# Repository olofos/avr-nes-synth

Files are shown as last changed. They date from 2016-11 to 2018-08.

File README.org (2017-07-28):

* NESSynth

  /NESSynth/ is an overcomplicated machine that plays NES music. /NESSynth/ currently supports four of the five channels present in the NES Audio Processing Unit (APU):
  - Two pulse, or square wave, channels
  - A triangle wave
  - A random noise channel

  There is currently no support for a DCM channel.

  /NESSynth/ has a menu system where the user can choose which game soundtrack is to be played.
  There is furthermore support for a playlist to which individual tracks can be added and played back.

** Hardware overview

  Each *channel* is processed separately by firmware running on an 8-bit ATMega88p microcontroller.
  An ATMega328p microcontroller acts as a central *controller*, reading track information from an SD card and writing the corresponding instructions to the channels.
  The controller is furthermore connected to an 128x64 pixel SSD1306 OLED display on which information about the current track, as well as a simple menu system, is displayed.
  User input is processed through an additional ATMega88p microcontroller which acts like an *io-bridge*, communicating with the main controller over I2C.
  The io-bridge is connected to four user buttons, four LEDs an a UART header for debugging.

  The following block diagram gives an overview of the architecture of /NESSynth/.

  #+HTML: <a href="doc/block-diagram.png"><img src="doc/block-diagram.png" width=800px></a>

*** 8-bit bus

   The controller communicates with the channels using an *8-bit parallel bus*.
   Writes to the bus are signalled on the *data clock* line.
   A rising clock signals that an address has been written on the bus, and a falling clock signals that a value that is to be written to the register at the previous address has been written on the bus.
   A new address or value is written every 33us, and the channels have to ensure that the data has been read from the bus within that time frame.

*** Frame clock

   In addition to the 8-bit bus, the controller provides the channel with a frame clock, which fires at a constant rate of 240 Hz.
   The frame clock is used to regularly update the output wave forms by applying the various effects such as the length counters and sweep units.

*** Channels

   Each channel emulates one of the channels on the NES APU.
   They react to writes to the corresponding registers appearing on the data bus and at each tick of the frame clock they clock the relevant output units in order to create effects such as sweep and envelope decay.

   The channels output sound at a frequency that is obtained by dividing the NTSC APU frequency of 1.789773 MHz by an integer, the /period/.
   The microcontrollers in the channels are clocked using a crystal with resonant frequency 14.3818 MHz, which is a multiple of the APU frequency.

   The PCBs of the channels have two jumpers, *CONF0* and *CONF1*, which can be used to configure which of the four APU channels the microcontroller is emulating.
   The possible settings are given in the following table.

   | CONF1      | CONF0      | Channel        |
   |------------+------------+----------------|
   | Fitted     | Fitted     | Square wave #1 |
   | Fitted     | Not fitted | Square wave #2 |
   | Not fitted | Fitted     | Triangle wave  |
   | Not fitted | Not fitted | Noise          |

   Each channel has a four bit R2R DAC that is used to construct the outgoing audio wave form.

   - Square wave channels

     The two square wave channels output a square wave with a duty cycle that can be set to 12.5%, 25%, 50% or 75%. The output volume of the square wave channels can be set to one of 16 levels, and can be modulated using the envelope decay unit. The square wave channels further support a sweep function to modulate the output frequency, as well as a length counter.

   - Triangle wave

     The triangle wave channel outputs a 32-step triangle wave of constant volume. For a given period, the frequency of the triangle wave is half of that of a square wave of the same period. The triangle wave channel supports a length counter and a linear counter which both can be used to limit the amount of time a note is played.

   - Noise channel

     The noise channel outputs noise that is generated using a linear feedback shift register. The feedback can be taken from two different taps of the shift registers. The volume of the noise channel can be configured to be constant, with 16 possible output levels, or can be varied over time using the envelope decay unit. The noise channel also supports a length counter.

*** Audio output

    The output of each channel is mixed together and then passed through a low pass filter with corner frequency 16 Hz and a high pass filter with corner frequency 16 kHz.
    The signal is the amplified using an LM386 audio amplifier before going to an 8 ohm speaker.

** Firmware

   The firmware for /NESSynth/ consists of three main pieces: the firmware for the main controller, the io-bridge and for the channels.
   The firmware is written using [[http://www.nongnu.org/avr-libc/user-manual/][avr-libc]] and compiled using avr-gcc.

   The controller has a menu system which is displayed on the OLED display.
   The menu system supports menus stored either on an SD card, in the flash memory of the controller, or in the EEPROM.
   It allows the user to play all the tracks from a particular game or to create a playlist with up to 128 tracks.
   The playlist is stored in the EEPROM of the controller.

   When playing a track, the controller reads the song data from the SD card where it is stored in a custom binary format (see below).
   The song data records the state of the APU registers at 60 Hz, and the controller outputs the data on the 8-bit bus.
   The song data is split into frames, and the controller plays the frames back at 60 Hz.

   The controller firmware includes a custom SD card and FAT32 drivers.
   The FAT32 driver does not read the FAT table into memory, which means that it has to search the table while reading data off the SD card.
   To improve performance when seeking in small files there is a cluster cache where the first few clusters in the currently open file.

   The firmware of the channels simply listens to writes to the registers relevant to the corresponding APU channel and puts out a wave form on the DAC.
   The channel firmware is heavily interrupt based.
   In order to improve the performance of the main timer interrupt, which is responsible for actually constructing the audio out signal, the interrupt handler has been written in assembly code.
   For clarity there is also a C version of the interrupt handler, which can be enabled by removing the ASMINTERRUPT flag in the Makefile of the channel firmware source code.

*** Song file format

   The binary file format is very simple.
   It consists of a number of two-byte records, with the first byte indicating an address, and the second byte the corresponding values.
   There are three special records

   | Address | Value | Meaning      |
   |---------+-------+--------------|
   |    0xF1 |  0xF1 | End of frame |
   |    0xFF |  0xFF | End of file  |
   |    0xFE |  0xFE | Loop         |

   The loop record is followed by a 16-bit byte address indicating which byte in the file to loop back to.

   In order to construct a data file from an NSF files, a player based on a custom version of the [[http://www.slack.net/~ant/libs/audio.html#Game_Music_Emu][Game_Music_Emu 0.5.2]] library is used.
   The custom NSF player outputs data in a text file.
   This data is then processed through a couple of simple programs which are used to detect loops in the track, and to convert the data into the binary file format described above.

** Acknowledgements

   The [[https://wiki.nesdev.com/w/index.php/APU][APU pages]] of the [[https://wiki.nesdev.com/][NesDev wiki]] have been invaluable for providing information about the inner workings of the NES APU, as has the [[http://nesdev.com/NESSOUND.txt][NESSOUND]] document by Brad Taylor.

   The NSF player that is used to create binary sound data files is based on the  [[http://www.slack.net/~ant/libs/audio.html#Game_Music_Emu][Game_Music_Emu 0.5.2]] library by Shay Green, which is licensed under the [[https://www.gnu.org/licenses/old-licenses/lgpl-2.1.en.html][GNU Lesser General Public License, Version 2.1]].

   The circular buffer implementation in lib/cbuf.h is inspired by the one in [[https://github.com/dhylands/TimerUART][TimerUART]].

   For 3d rendering of the boards, 3d models from [[https://github.com/ab2tech/KiCad][ab2tech]], which are licensed under [[http://creativecommons.org/licenses/by-nc-sa/3.0/deed.en_US][Creative Commons Attribution-NonCommercial-ShareAlike 3.0 Unported License]], and from [[https://github.com/JorgeAparicio/libKiCad][libKiCad]], which are licensed under [[hardware/lib/3d_models/walter/license.txt][Creative Commons license v3.0, Attribution-Share Alike]], have been used.

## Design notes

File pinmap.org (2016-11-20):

* Main board
  PB0 DCLK
  PB1 SD_CD
  PB2 SD_CS
  PB3 MOSI
  PB4 MISO
  PB5 SCK

  PC0 IO_INT
  PC1 LED
  PC2 CH_RESET
  PC3 FCLK
  PC4 SDA
  PC5 SCL

  PD0 BUS0 + RX
  PD1 BUS1
  PD2 BUS2
  PD3 BUS3
  PD4 BUS4
  PD5 BUS5
  PD6 BUS6
  PD7 BUS7

* IO board
  PB0 SW1
  PB2 SW2
  PB6 SW3
  PB7 SW4

  PC0 LED1
  PC1 LED2
  PC2 LED3
  PC3 LED4
  PC4 SDA
  PC5 SCL

  PD0 RX
  PD1 TX
  PD2 IO_INT

* Channel
  PB0 DCLK
  PB1 CONF0
  PB2 CONF1
  
  PC0 DAC0
  PC1 DAC1
  PC2 DAC2
  PC3 DAC3
  PC4 LED
  PC5 FCLK

  PD0 BUS0
  PD1 BUS1
  PD2 BUS2
  PD3 BUS3
  PD4 BUS4
  PD5 BUS5
  PD6 BUS6
  PD7 BUS7

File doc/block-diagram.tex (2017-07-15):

\documentclass{standalone}

\usepackage{tikz}
\usetikzlibrary{arrows,calc,shapes}

\renewcommand{\familydefault}{\sfdefault}

\tikzstyle{block} = [draw,rounded corners,fill=blue!20,inner sep=0pt]
\tikzstyle{io-block} = [draw,rounded corners,fill=red!20,inner sep=0pt]
\tikzstyle{mixer} = [regular polygon, regular polygon sides=3,draw, fill=blue!20, text width=1em,inner sep=1mm, outer sep=0mm, shape border rotate=-90]

\begin{document}

\begin{tikzpicture}
%  \draw (-10,-1.75) rectangle (4.9,7.2);
  
  \node [block,minimum width=4cm,minimum height=1.75cm] (controller) at (0,0) {\parbox{1.4cm}{\centering controller \\ \tiny atmega328p}};
  \node [block,minimum width=1.75cm,minimum height=1.75cm] (io-bridge) at (-7,0) {\parbox{1.4cm}{\centering io-bridge \\ \tiny atmega88p}};

  \node [block,minimum width=1.75cm,minimum height=1.75cm] (channel-1) at (-8,4) {\parbox{1.75cm}{\centering channel 1 \\ \tiny atmega88p}};
  \node [block,minimum width=1.75cm,minimum height=1.75cm] (channel-2) at (-6,4) {\parbox{1.75cm}{\centering channel 2 \\ \tiny atmega88p}};
  \node [block,minimum width=1.75cm,minimum height=1.75cm] (channel-3) at (-4,4) {\parbox{1.75cm}{\centering channel 3 \\ \tiny atmega88p}};
  \node [block,minimum width=1.75cm,minimum height=1.75cm] (channel-4) at (-2,4) {\parbox{1.75cm}{\centering channel 4 \\ \tiny atmega88p}};

  \node [io-block,minimum width=0.9cm,minimum height=0.4cm] (OLED) at ($(controller.west)!0.5!(io-bridge.east)-(0,1.5)$) {\tiny OLED};
  \node [io-block,minimum width=0.9cm,minimum height=0.4cm] (UART) at ($(io-bridge)+(1.5,-1.5)$) {\tiny UART};
  \node [io-block,minimum width=0.9cm,minimum height=0.4cm] (LEDs) at ($(io-bridge)+(0,-1.5)$) {\tiny LEDs};
  \node [io-block,minimum width=0.9cm,minimum height=0.4cm] (buttons) at ($(io-bridge)+(-1.5,-1.5)$) {\tiny buttons};

  \coordinate (controller-i2c-c) at (controller.west);
  \coordinate (controller-spi-c) at (controller.east);
  \coordinate (controller-bus-c) at ($(controller.north)+(-0.55,0)$);
  \coordinate (controller-dclk-c) at ($(controller.north)+(-1.7,0)$);
  \coordinate (controller-fclk-c) at ($(controller.north)+(+0.55,0)$);
  \coordinate (controller-ch-res-c) at ($(controller.north)+(+1.7,0)$);
  \coordinate (controller-io-int-c) at ($(controller.west)+(0,0.5)$);

  \coordinate (io-bridge-spi-c) at ($(io-bridge.west)+(0,0.5)$);
  \coordinate (io-bridge-buttons-c) at ($(io-bridge.west)-(0,0.5)$);
  \coordinate (io-bridge-UART-c) at ($(io-bridge.east)-(0,0.5)$);
  \coordinate (io-bridge-LEDs-c) at (io-bridge.south);
  \coordinate (io-bridge-io-int-c) at ($(io-bridge.east)+(0,0.5)$);

  \node [mixer] (mixer) at (0,6.5) {};
  \node at ($(mixer)-(0,0)$) {\tiny mixer};

  \coordinate (audio-out-1) at ($(mixer.west)+(0,0.375)$);
  \coordinate (audio-out-2) at ($(mixer.west)+(0,0.125)$);
  \coordinate (audio-out-3) at ($(mixer.west)-(0,0.125)$);
  \coordinate (audio-out-4) at ($(mixer.west)-(0,0.375)$);

  \foreach \n in {1,2,3,4} {
    \coordinate (channel-\n-dclk) at ($(channel-\n.south)+(-0.5,0)$);
    \coordinate (channel-\n-bus) at ($(channel-\n.south)+(-0.125,0)$);
    \coordinate (channel-\n-fclk) at ($(channel-\n.south)+(+0.125,0)$);
    \coordinate (channel-\n-reset) at ($(channel-\n.south)+(+0.5,0)$);

    \coordinate (channel-\n-spi-c) at ($(channel-\n.north)+(-0.5,0)$);
    \coordinate (channel-\n-audio-c) at ($(channel-\n.north)+(+0.5,0)$);

    \node (channel-\n-spi) at ($(channel-\n-spi-c)+(0,0.1)$) [draw,rounded corners,anchor=south] {\tiny SPI};
    \node (channel-\n-audio) at ($(channel-\n-audio-c)+(0,0.1)$) [draw,rounded corners,anchor=south] {\tiny audio};

    \draw (channel-\n-spi-c) -- (channel-\n-spi);
    \draw (channel-\n-audio-c) -- (channel-\n-audio);

    \node [io-block,minimum width=0.9cm,minimum height=0.4cm] (channel-\n-ISP) at ($(channel-\n-spi.north)+(0,0.5)$) {\tiny ISP};
    \draw [<->] (channel-\n-spi) -- (channel-\n-ISP);

    \draw [rounded corners,->] (channel-\n-audio) |- (audio-out-\n);
  }

  \node [io-block,minimum width=1.2cm,minimum height=0.4cm] (audio-out) at ($(mixer.east)+(1.5,0)$) {\tiny audio out};

  \draw [->] (mixer.east) -- (audio-out);

  \node (controller-i2c) at ($(controller-i2c-c)+(-0.1,0)$) [draw,rounded corners,anchor=east] {\tiny I2C};
  \node (controller-spi) at ($(controller-spi-c)+(+0.1,0)$) [draw,rounded corners,anchor=west] {\tiny SPI};

  \node [io-block,minimum width=0.9cm,minimum height=0.4cm] (SD-card) at ($(controller-spi)+(1,-1.5)$) {\tiny SD card};
  \node [io-block,minimum width=0.9cm,minimum height=0.4cm] (controller-ISP) at ($(controller-spi)+(2,0)$) {\tiny ISP};

  \node (io-bridge-spi) at ($(io-bridge-spi-c)+(-0.1,0)$) [draw,rounded corners,anchor=east] {\tiny SPI};

  \node [io-block,minimum width=0.9cm,minimum height=0.4cm] (io-bridge-ISP) at ($(io-bridge-spi)-(1.25,0)$) {\tiny ISP};
  
  \node (controller-bus) at ($(controller-bus-c)+(0,0.1)$) [draw,rounded corners,anchor=south] {\parbox{0.75cm}{\centering \tiny 8-bit \\ bus}};
  \node (controller-dclk) at ($(controller-dclk-c)+(0,0.1)$) [draw,rounded corners,anchor=south] {\parbox{0.75cm}{\centering \tiny Data \\ clock}};
  \node (controller-fclk) at ($(controller-fclk-c)+(0,0.1)$) [draw,rounded corners,anchor=south] {\parbox{0.75cm}{\centering \tiny Frame \\ clock}};
  \node (controller-ch-res) at ($(controller-ch-res-c)+(0,0.1)$) [draw,rounded corners,anchor=south] {\parbox{0.85cm}{\centering \tiny Channel \\ reset}};
  \node (controller-io-int) at ($(controller-io-int-c)-(0.1,0)$) [draw,rounded corners,anchor=east] {\parbox{0.75cm}{\centering \tiny IO int}};

  \draw (controller-spi-c) -- (controller-spi);
  \draw (controller-i2c-c) -- (controller-i2c);
  \draw (controller-dclk-c) -- (controller-dclk);
  \draw (controller-fclk-c) -- (controller-fclk);
  \draw (controller-ch-res-c) -- (controller-ch-res);
  \draw (controller-io-int-c) -- (controller-io-int);

  \draw [->] (io-bridge-io-int-c) -- (controller-io-int);

  \draw (io-bridge-spi-c) -- (io-bridge-spi);

  \foreach \x in {-0.35, -0.25, -0.15, -0.05, 0.05, 0.15, 0.25, 0.35} {
    \draw ($(controller-bus-c)+(\x,0)$) -- ($(controller-bus.south)+(\x,0)$);
  }
  
  \draw [<->] ($(controller-i2c.west)+(0,0.05)$) -- ($(io-bridge.east)+(0,0.05)$);
  \draw [rounded corners,->] ($(controller-i2c.west)-(0,0.05)$) -| (OLED.north);

  \draw [rounded corners,<->] (controller-spi.east) -| (SD-card.north);
  \draw [rounded corners,->] (controller-spi.east) -- (controller-ISP.west);

  \draw [rounded corners,<->] (io-bridge-spi.west) -- (io-bridge-ISP.east);

  \draw [rounded corners,<->] (io-bridge-UART-c) -| (UART);
  \draw [rounded corners,->] (io-bridge-LEDs-c) -- (LEDs);
  \draw [rounded corners,<-] (io-bridge-buttons-c) -| (buttons);

  \foreach \n in {1,2,3,4} {
    \draw [rounded corners,->] (controller-dclk.north) -- ($(controller-dclk.north)+(0,0.5)$) -| (channel-\n-dclk);
    \draw [rounded corners,->] (controller-bus.north) -- ($(controller-bus.north)+(0,0.75)$) -| (channel-\n-bus);
    \draw [rounded corners,->] (controller-fclk.north) -- ($(controller-fclk.north)+(0,1)$) -| (channel-\n-fclk);
    \draw [rounded corners,->] (controller-ch-res.north) -- ($(controller-ch-res.north)+(0,1.25)$) -| (channel-\n-reset);
  }

  \coordinate (sw) at (current bounding box.south west);
  \coordinate (ne) at (current bounding box.north east);
  
  \useasboundingbox ($(sw)-(0.25,0.25)$) rectangle ($(ne)+(0.25,0.25)$);
  
\end{tikzpicture}

\end{document}

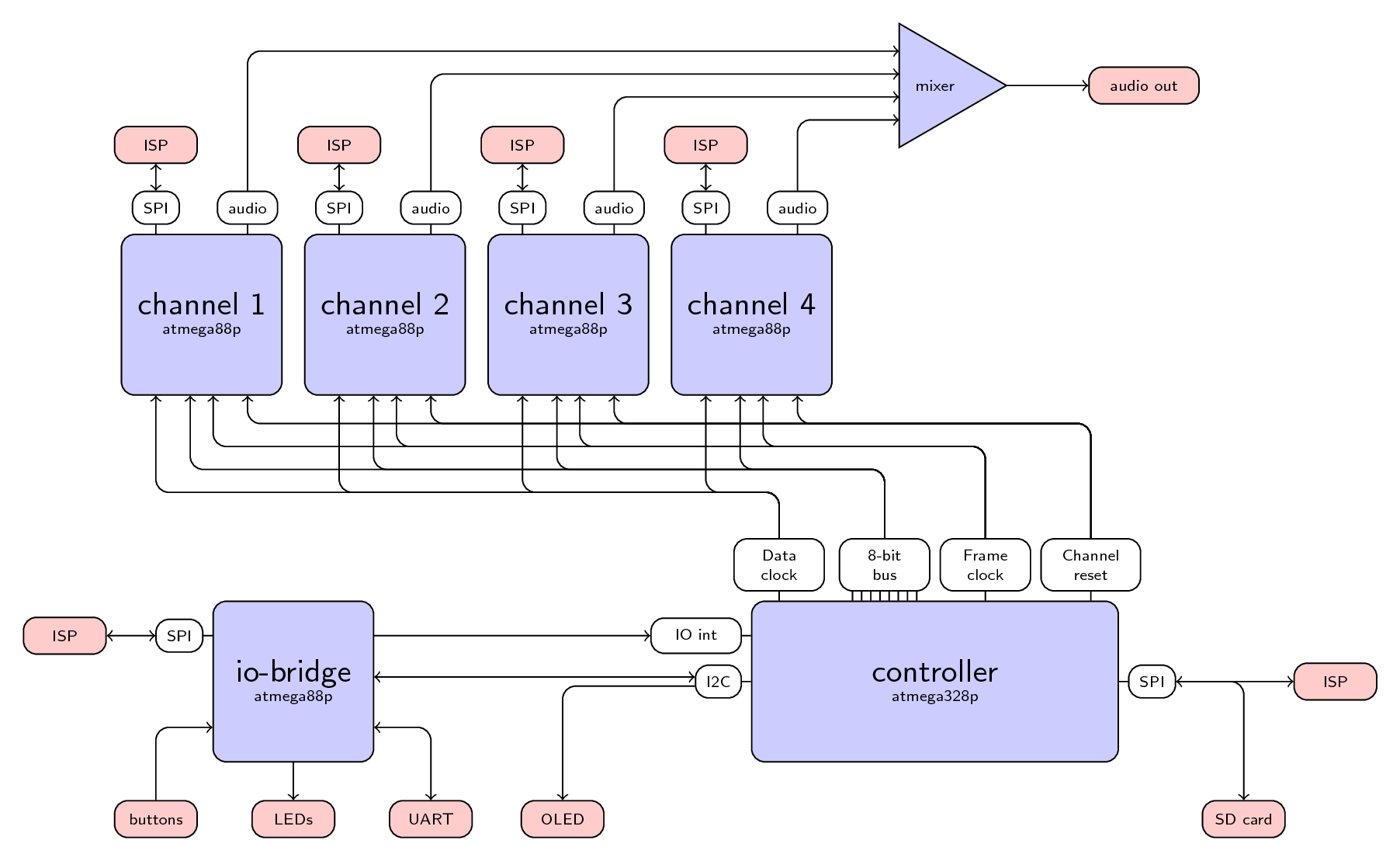
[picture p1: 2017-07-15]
doc/block-diagram.png

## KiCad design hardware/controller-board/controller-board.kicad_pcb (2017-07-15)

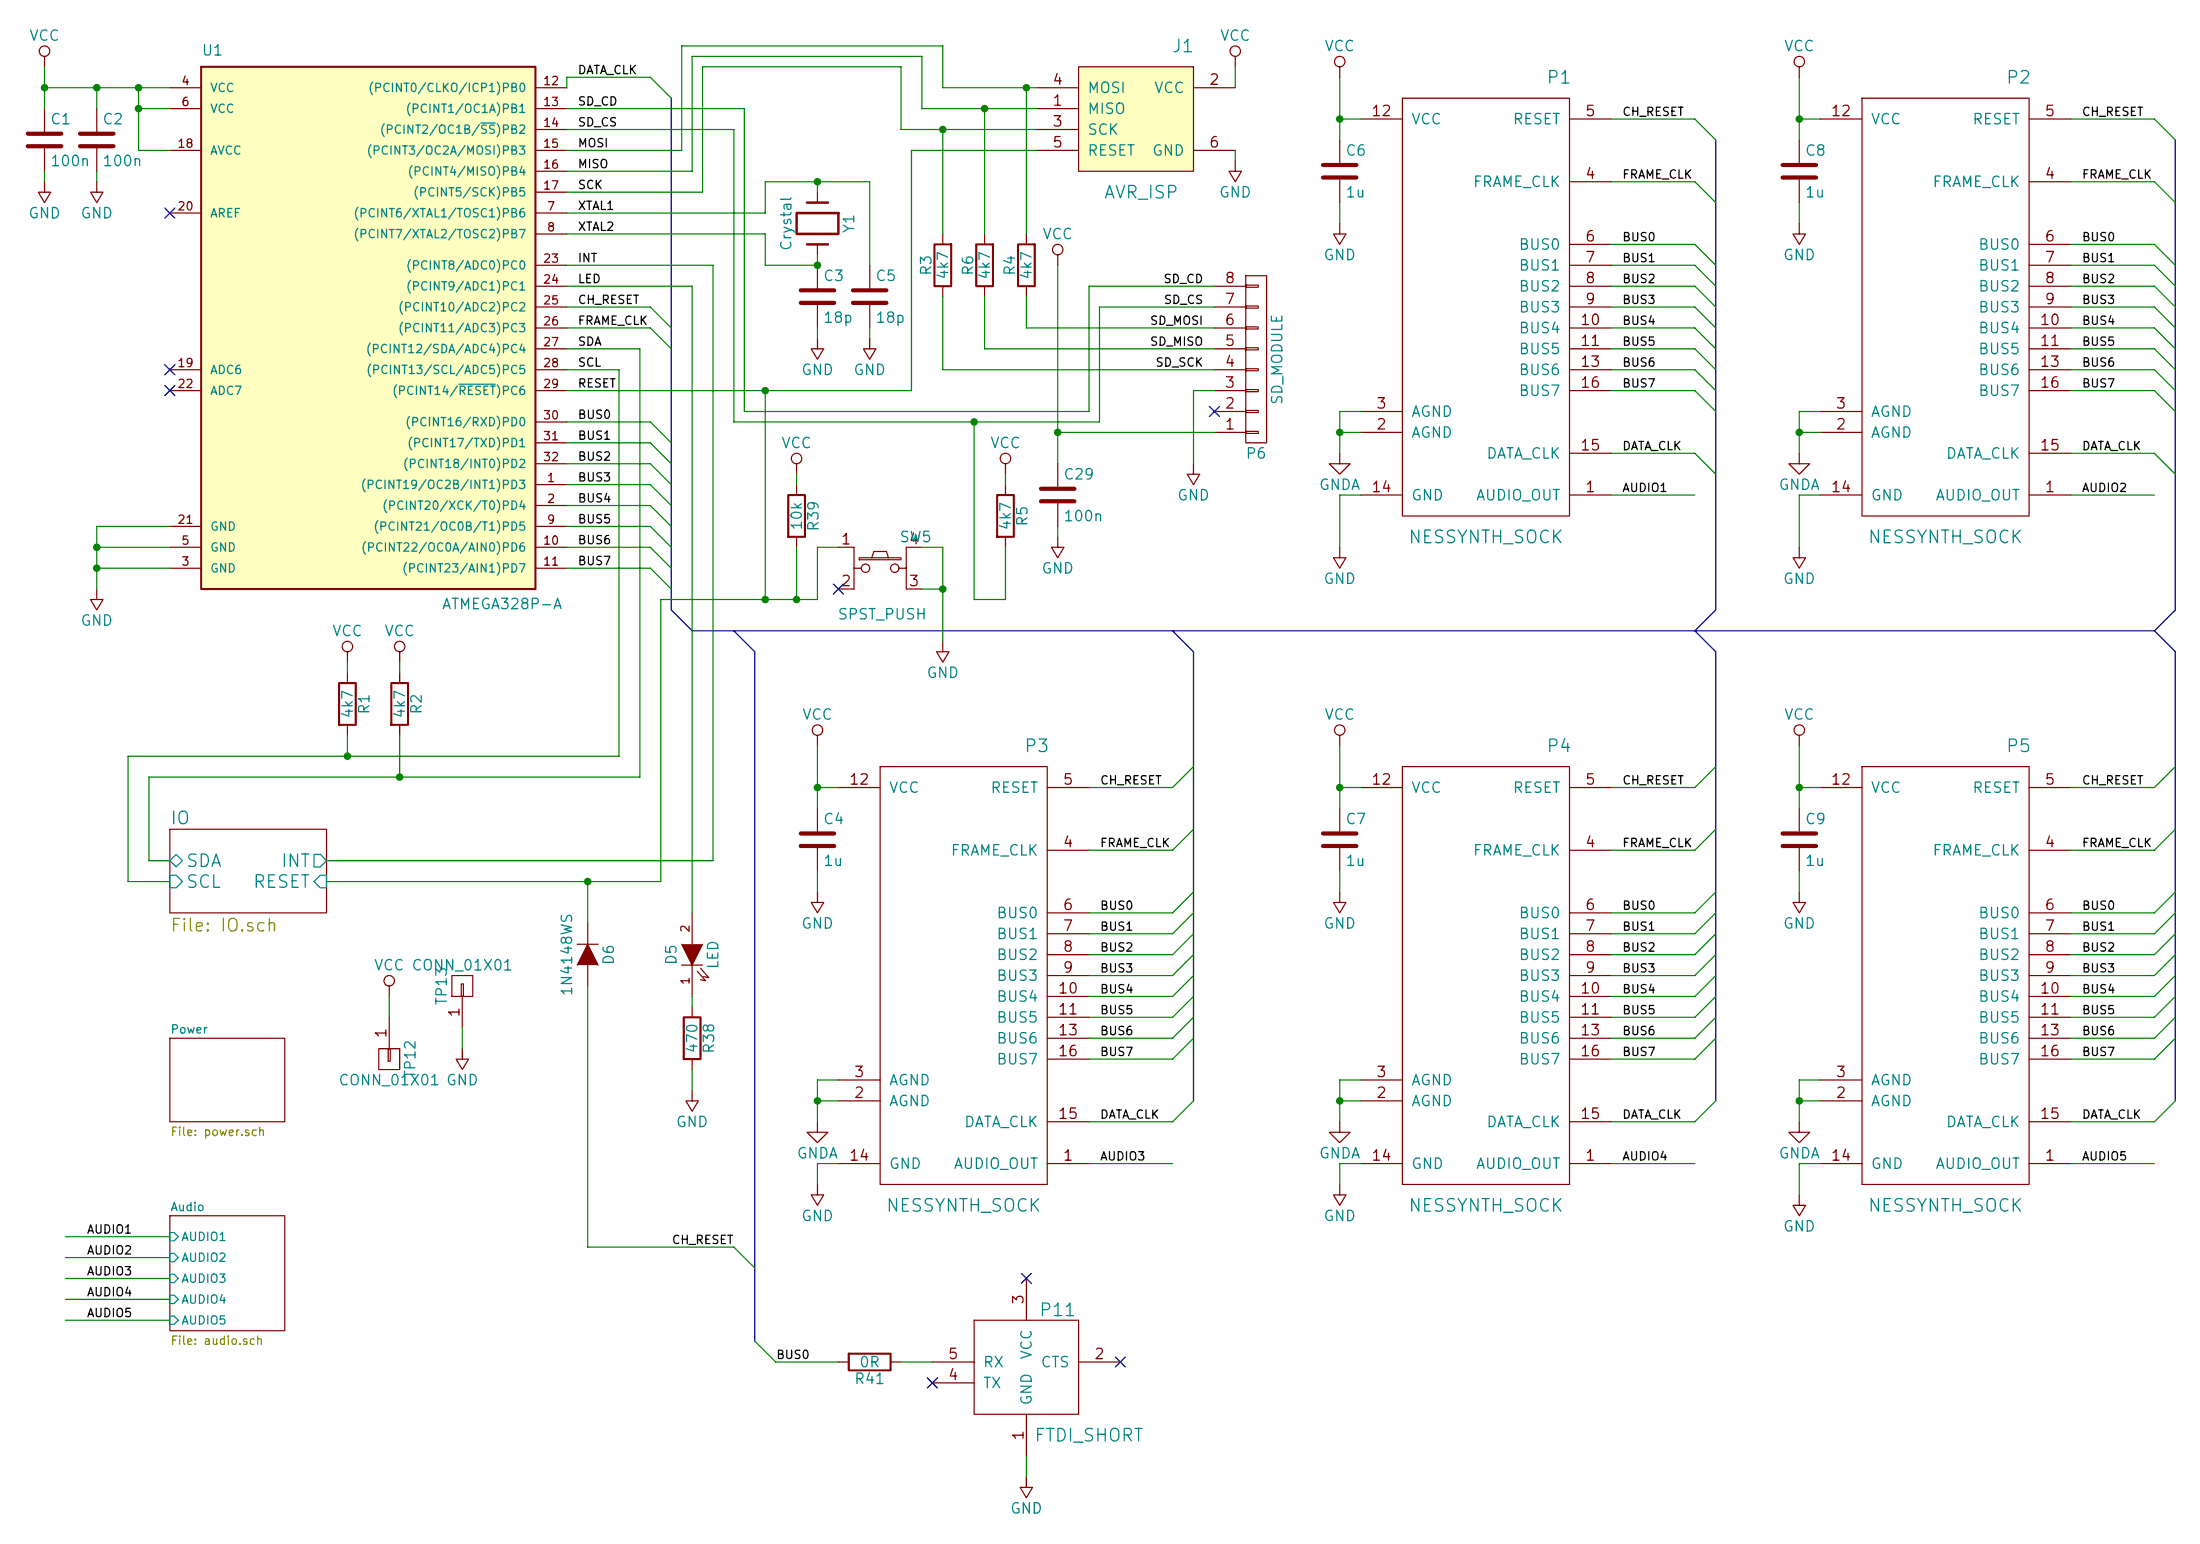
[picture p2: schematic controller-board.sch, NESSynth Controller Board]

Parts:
C1, C2, C29: 100n; C_0805_HandSoldering
C3, C5: 18p; C_0805_HandSoldering
C4, C6, C7, C8, C9: 1u; C_0805_HandSoldering
D5: LED; LED_0805
D6: 1N4148WS; SOD-323
J1: AVR_ISP; AVR_ISP_SMALL
P1, P2, P3, P4, P5: NESSYNTH_SOCK; Socket_Strip_Straight_2x08
P6: SD_MODULE; Socket_Strip_Straight_1x08
P11: FTDI_SHORT; Pin_Header_Straight_1x05
R1, R2, R3, R4, R5, R6: 4k7; R_0805_HandSoldering
R38: 470; R_0805_HandSoldering
R39: 10k; R_0805_HandSoldering
R41: 0R; R_0805_HandSoldering
SW5: SPST_PUSH; SW_PUSH_SMALL_4
TP12: CONN_01X01; Measurement_Point_Round-SMD-Pad_Small
TP13: CONN_01X01; Measurement_Point_Square-SMD-Pad_Small
U1: ATMEGA328P-A; TQFP-32_7x7mm_Pitch0.8mm
Y1: Crystal; Crystal_HC49-U_Vertical

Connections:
/Audio/AUDIO1: P1.1 (AUDIO_OUT); also elsewhere on the board
/Audio/AUDIO2: P2.1 (AUDIO_OUT); also elsewhere on the board
/Audio/AUDIO3: P3.1 (AUDIO_OUT); also elsewhere on the board
/Audio/AUDIO4: P4.1 (AUDIO_OUT); also elsewhere on the board
/Audio/AUDIO5: P5.1 (AUDIO_OUT); also elsewhere on the board
/BUS0: P1.6 (BUS0), P2.6 (BUS0), P3.6 (BUS0), P4.6 (BUS0), P5.6 (BUS0), R41.2, U1.30 ((PCINT16/RXD)PD0)
/BUS1: P1.7 (BUS1), P2.7 (BUS1), P3.7 (BUS1), P4.7 (BUS1), P5.7 (BUS1), U1.31 ((PCINT17/TXD)PD1)
/BUS2: P1.8 (BUS2), P2.8 (BUS2), P3.8 (BUS2), P4.8 (BUS2), P5.8 (BUS2), U1.32 ((PCINT18/INT0)PD2)
/BUS3: P1.9 (BUS3), P2.9 (BUS3), P3.9 (BUS3), P4.9 (BUS3), P5.9 (BUS3), U1.1 ((PCINT19/OC2B/INT1)PD3)
/BUS4: P1.10 (BUS4), P2.10 (BUS4), P3.10 (BUS4), P4.10 (BUS4), P5.10 (BUS4), U1.2 ((PCINT20/XCK/T0)PD4)
/BUS5: P1.11 (BUS5), P2.11 (BUS5), P3.11 (BUS5), P4.11 (BUS5), P5.11 (BUS5), U1.9 ((PCINT21/OC0B/T1)PD5)
/BUS6: P1.13 (BUS6), P2.13 (BUS6), P3.13 (BUS6), P4.13 (BUS6), P5.13 (BUS6), U1.10 ((PCINT22/OC0A/AIN0)PD6)
/BUS7: P1.16 (BUS7), P2.16 (BUS7), P3.16 (BUS7), P4.16 (BUS7), P5.16 (BUS7), U1.11 ((PCINT23/AIN1)PD7)
/CH_RESET: D6.2 (A), P1.5 (RESET), P2.5 (RESET), P3.5 (RESET), P4.5 (RESET), P5.5 (RESET), U1.25 ((PCINT10/ADC2)PC2)
/DATA_CLK: P1.15 (DATA_CLK), P2.15 (DATA_CLK), P3.15 (DATA_CLK), P4.15 (DATA_CLK), P5.15 (DATA_CLK), U1.12 ((PCINT0/CLKO/ICP1)PB0)
/FRAME_CLK: P1.4 (FRAME_CLK), P2.4 (FRAME_CLK), P3.4 (FRAME_CLK), P4.4 (FRAME_CLK), P5.4 (FRAME_CLK), U1.26 ((PCINT11/ADC3)PC3)
/IO/INT: U1.23 ((PCINT8/ADC0)PC0); also elsewhere on the board
/IO/RESET: D6.1 (K), J1.5 (RESET), R39.2, SW5.1 (A1), U1.29 ((PCINT14/~RESET~)PC6); also elsewhere on the board
/IO/SCL: R1.2, U1.28 ((PCINT13/SCL/ADC5)PC5); also elsewhere on the board
/IO/SDA: R2.2, U1.27 ((PCINT12/SDA/ADC4)PC4); also elsewhere on the board
/LED: D5.2 (A), U1.24 ((PCINT9/ADC1)PC1)
/MISO: J1.1 (MISO), R6.2, U1.16 ((PCINT4/MISO)PB4)
/MOSI: J1.4 (MOSI), R4.2, U1.15 ((PCINT3/OC2A/MOSI)PB3)
/SCK: J1.3 (SCK), R3.2, U1.17 ((PCINT5/SCK)PB5)
/SD_CD: P6.8, U1.13 ((PCINT1/OC1A)PB1)
/SD_CS: P6.7, R5.2, U1.14 ((PCINT2/OC1B/~SS~)PB2)
/SD_MISO: P6.5, R6.1
/SD_MOSI: P6.6, R4.1
/SD_SCK: P6.4, R3.1
/XTAL1: C5.1, U1.7 ((PCINT6/XTAL1/TOSC1)PB6), Y1.1
/XTAL2: C3.1, U1.8 ((PCINT7/XTAL2/TOSC2)PB7), Y1.2
GND: C1.2, C2.2, C3.2, C4.2, C5.2, C6.2, C7.2, C8.2, C9.2, C29.2, J1.6 (GND), P1.2 (AGND), P1.3 (AGND), P1.14 (GND), P2.2 (AGND), P2.3 (AGND), P2.14 (GND), P3.2 (AGND), P3.3 (AGND), P3.14 (GND), P4.2 (AGND), P4.3 (AGND), P4.14 (GND), P5.2 (AGND), P5.3 (AGND), P5.14 (GND), P6.3, P11.1 (GND), R38.2, SW5.3 (B2), SW5.4 (B1), TP13.1, U1.3 (GND), U1.5 (GND), U1.21 (GND); also elsewhere on the board
unnamed: D5.1 (K), R38.1
unnamed: P11.5 (RX), R41.1
VCC: C1.1, C2.1, C4.1, C6.1, C7.1, C8.1, C9.1, C29.1, J1.2 (VCC), P1.12 (VCC), P2.12 (VCC), P3.12 (VCC), P4.12 (VCC), P5.12 (VCC), P6.1, R1.1, R2.1, R5.1, R39.1, TP12.1, U1.4 (VCC), U1.6 (VCC), U1.18 (AVCC); also elsewhere on the board

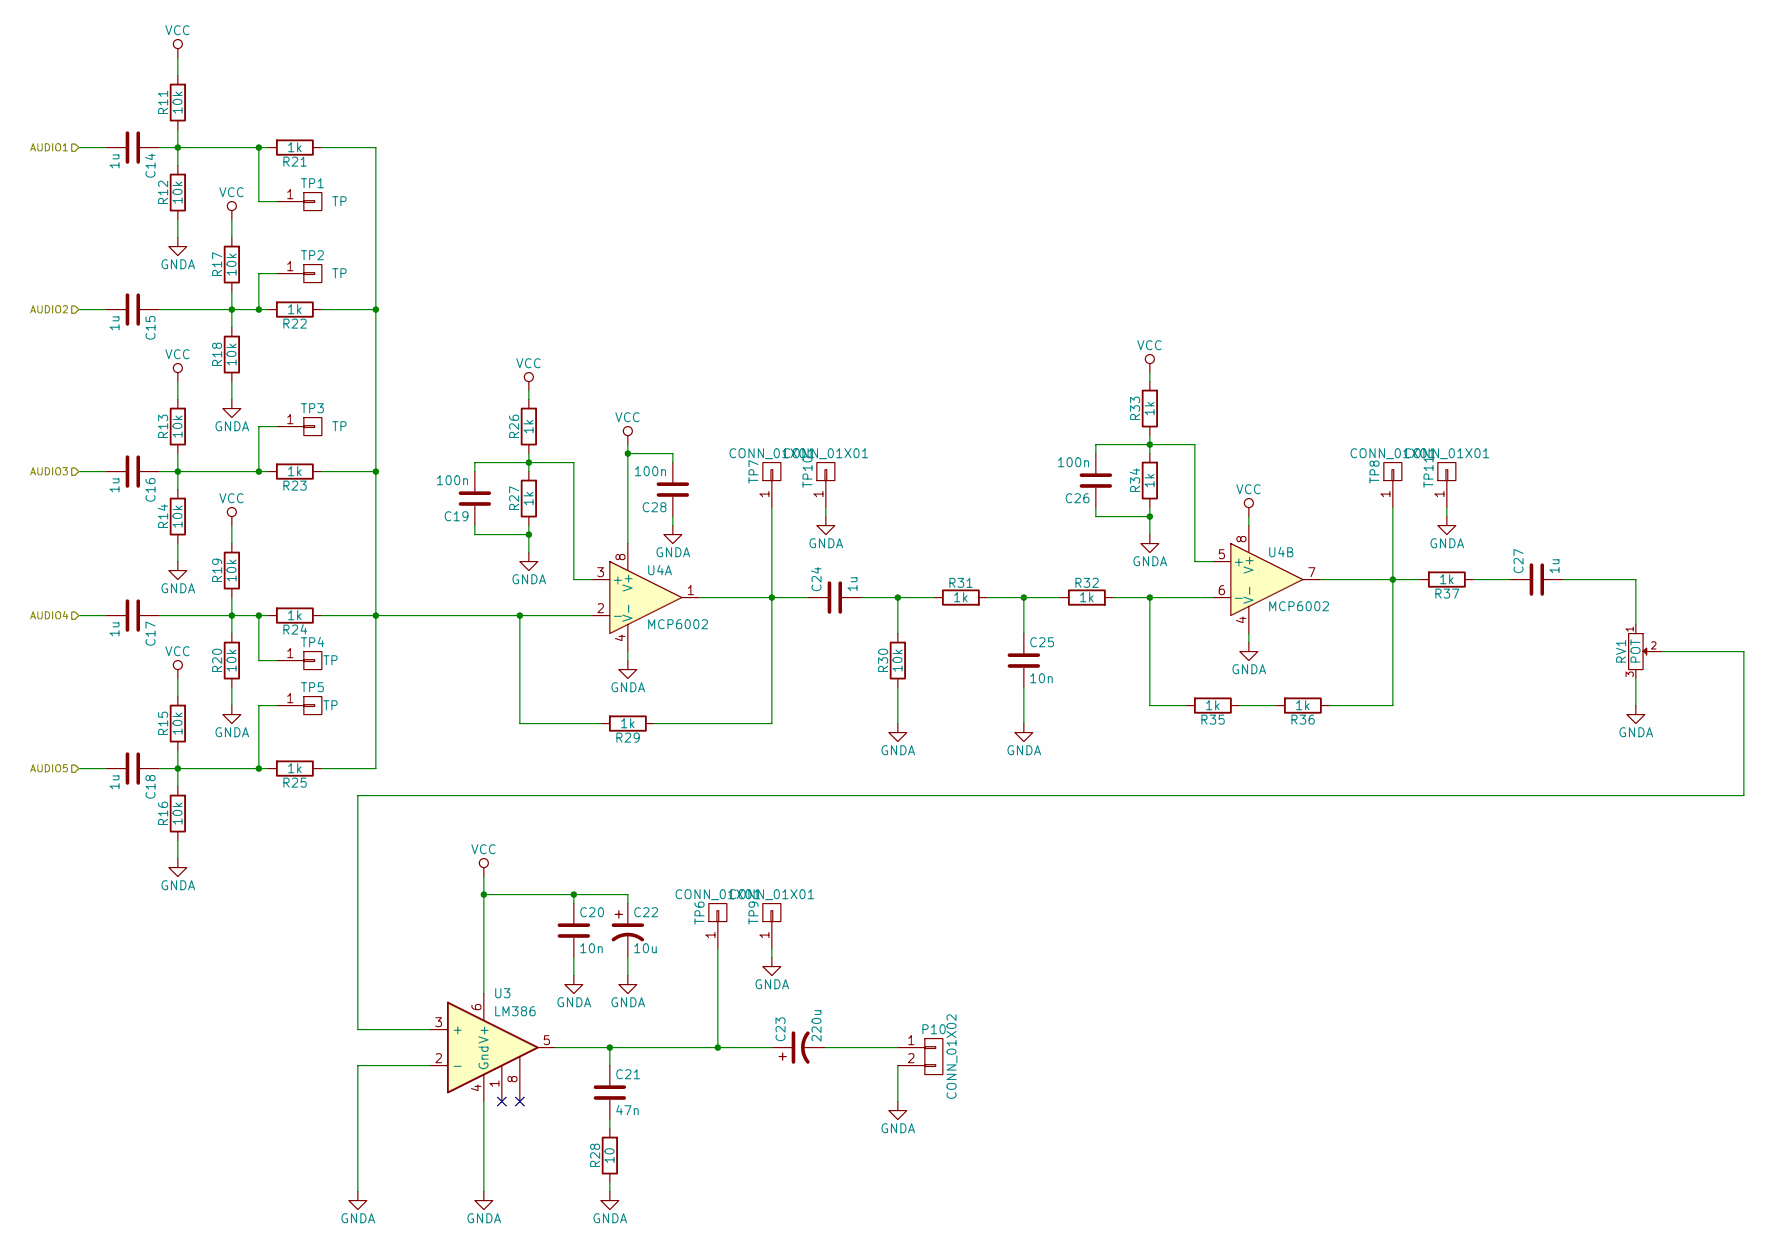
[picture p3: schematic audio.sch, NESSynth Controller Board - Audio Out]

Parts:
C14, C15, C16, C17, C18, C24, C27: 1u; C_0805_HandSoldering
C19, C26, C28: 100n; C_0805_HandSoldering
C20, C25: 10n; C_0805_HandSoldering
C21: 47n; C_0805_HandSoldering
C22: 10u; c_elec_6.3x5.7
C23: 220u; c_elec_6.3x5.7
P10: CONN_01X02; TerminalBlock_Pheonix_MPT-2.54mm_2pol
R11, R12, R13, R14, R15, R16, R17, R18, R19, R20, R30: 10k; R_0805_HandSoldering
R21, R22, R23, R24, R25, R26, R27, R29, R31, R32, R33, R34, R35, R36, R37: 1k; R_0805_HandSoldering
R28: 10; R_0805_HandSoldering
RV1: POT; Potentiometer_Alps-RK16-single_largePads
TP1, TP2, TP3, TP4, TP5: TP; TEST_POINT_THD
TP6, TP7, TP8: CONN_01X01; Measurement_Point_Round-SMD-Pad_Small
TP9, TP10, TP11: CONN_01X01; Measurement_Point_Square-SMD-Pad_Small
U3: LM386; SOIC-8_3.9x4.9mm_Pitch1.27mm
U4: MCP6002; SOIC-8_3.9x4.9mm_Pitch1.27mm

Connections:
/Audio/AUDIO1: C14.2; also elsewhere on the board
/Audio/AUDIO2: C15.2; also elsewhere on the board
/Audio/AUDIO3: C16.2; also elsewhere on the board
/Audio/AUDIO4: C17.2; also elsewhere on the board
/Audio/AUDIO5: C18.2; also elsewhere on the board
GND: C19.1, C20.2, C22.2, C25.2, C26.1, C28.1, P10.2, R12.1, R14.1, R16.1, R18.1, R20.1, R27.1, R28.1, R30.1, R34.1, RV1.3, TP9.1, TP10.1, TP11.1, U3.2 (-), U3.4 (Gnd), U4.4 (V-); also elsewhere on the board
unnamed: C14.1, R11.1, R12.2, R21.2, TP1.1
unnamed: C15.1, R17.1, R18.2, R22.2, TP2.1
unnamed: C16.1, R13.1, R14.2, R23.2, TP3.1
unnamed: C17.1, R19.1, R20.2, R24.2, TP4.1
unnamed: C18.1, R15.1, R16.2, R25.2, TP5.1
unnamed: C19.2, R26.1, R27.2, U4.3 (+)
unnamed: C21.1, C23.1, TP6.1, U3.5
unnamed: C21.2, R28.2
unnamed: C23.2, P10.1
unnamed: C24.1, R29.1, TP7.1, U4.1
unnamed: C24.2, R30.2, R31.1
unnamed: C25.1, R31.2, R32.1
unnamed: C26.2, R33.1, R34.2, U4.5 (+)
unnamed: C27.1, R37.1
unnamed: C27.2, RV1.1
unnamed: R21.1, R22.1, R23.1, R24.1, R25.1, R29.2, U4.2 (-)
unnamed: R32.2, R35.2, U4.6 (-)
unnamed: R35.1, R36.2
unnamed: R36.1, R37.2, TP8.1, U4.7
unnamed: RV1.2, U3.3 (+)
VCC: C20.1, C22.1, C28.2, R11.2, R13.2, R15.2, R17.2, R19.2, R26.2, R33.2, U3.6 (V+), U4.8 (V+); also elsewhere on the board

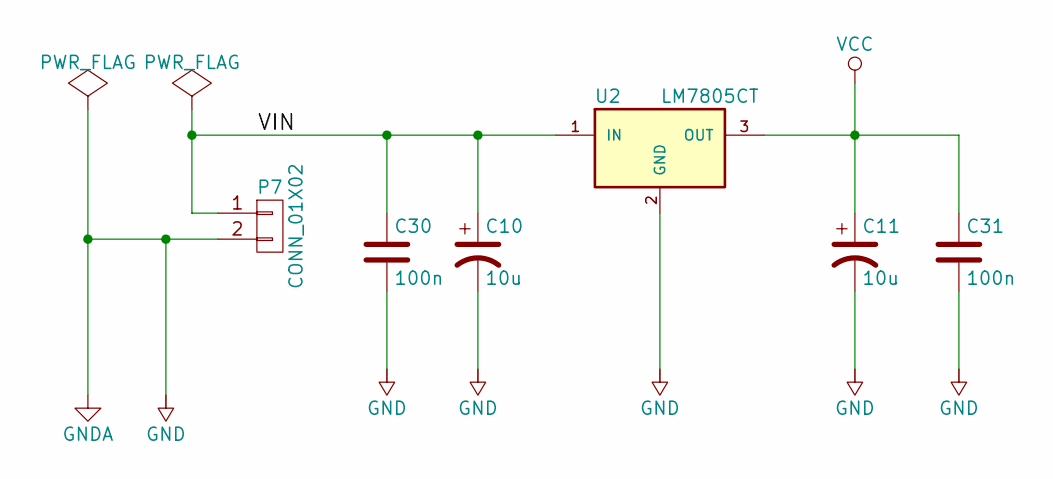
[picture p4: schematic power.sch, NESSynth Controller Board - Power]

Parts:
C10, C11: 10u; c_elec_6.3x5.7
C30, C31: 100n; C_0805_HandSoldering
P7: CONN_01X02; Pin_Header_Straight_1x02
U2: LM7805CT; TO-220_Neutral123_Vertical

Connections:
/Power/VIN: C10.1, C30.1, P7.1, U2.1 (IN)
GND: C10.2, C11.2, C30.2, C31.2, P7.2, U2.2 (GND); also elsewhere on the board
VCC: C11.1, C31.1, U2.3 (OUT); also elsewhere on the board

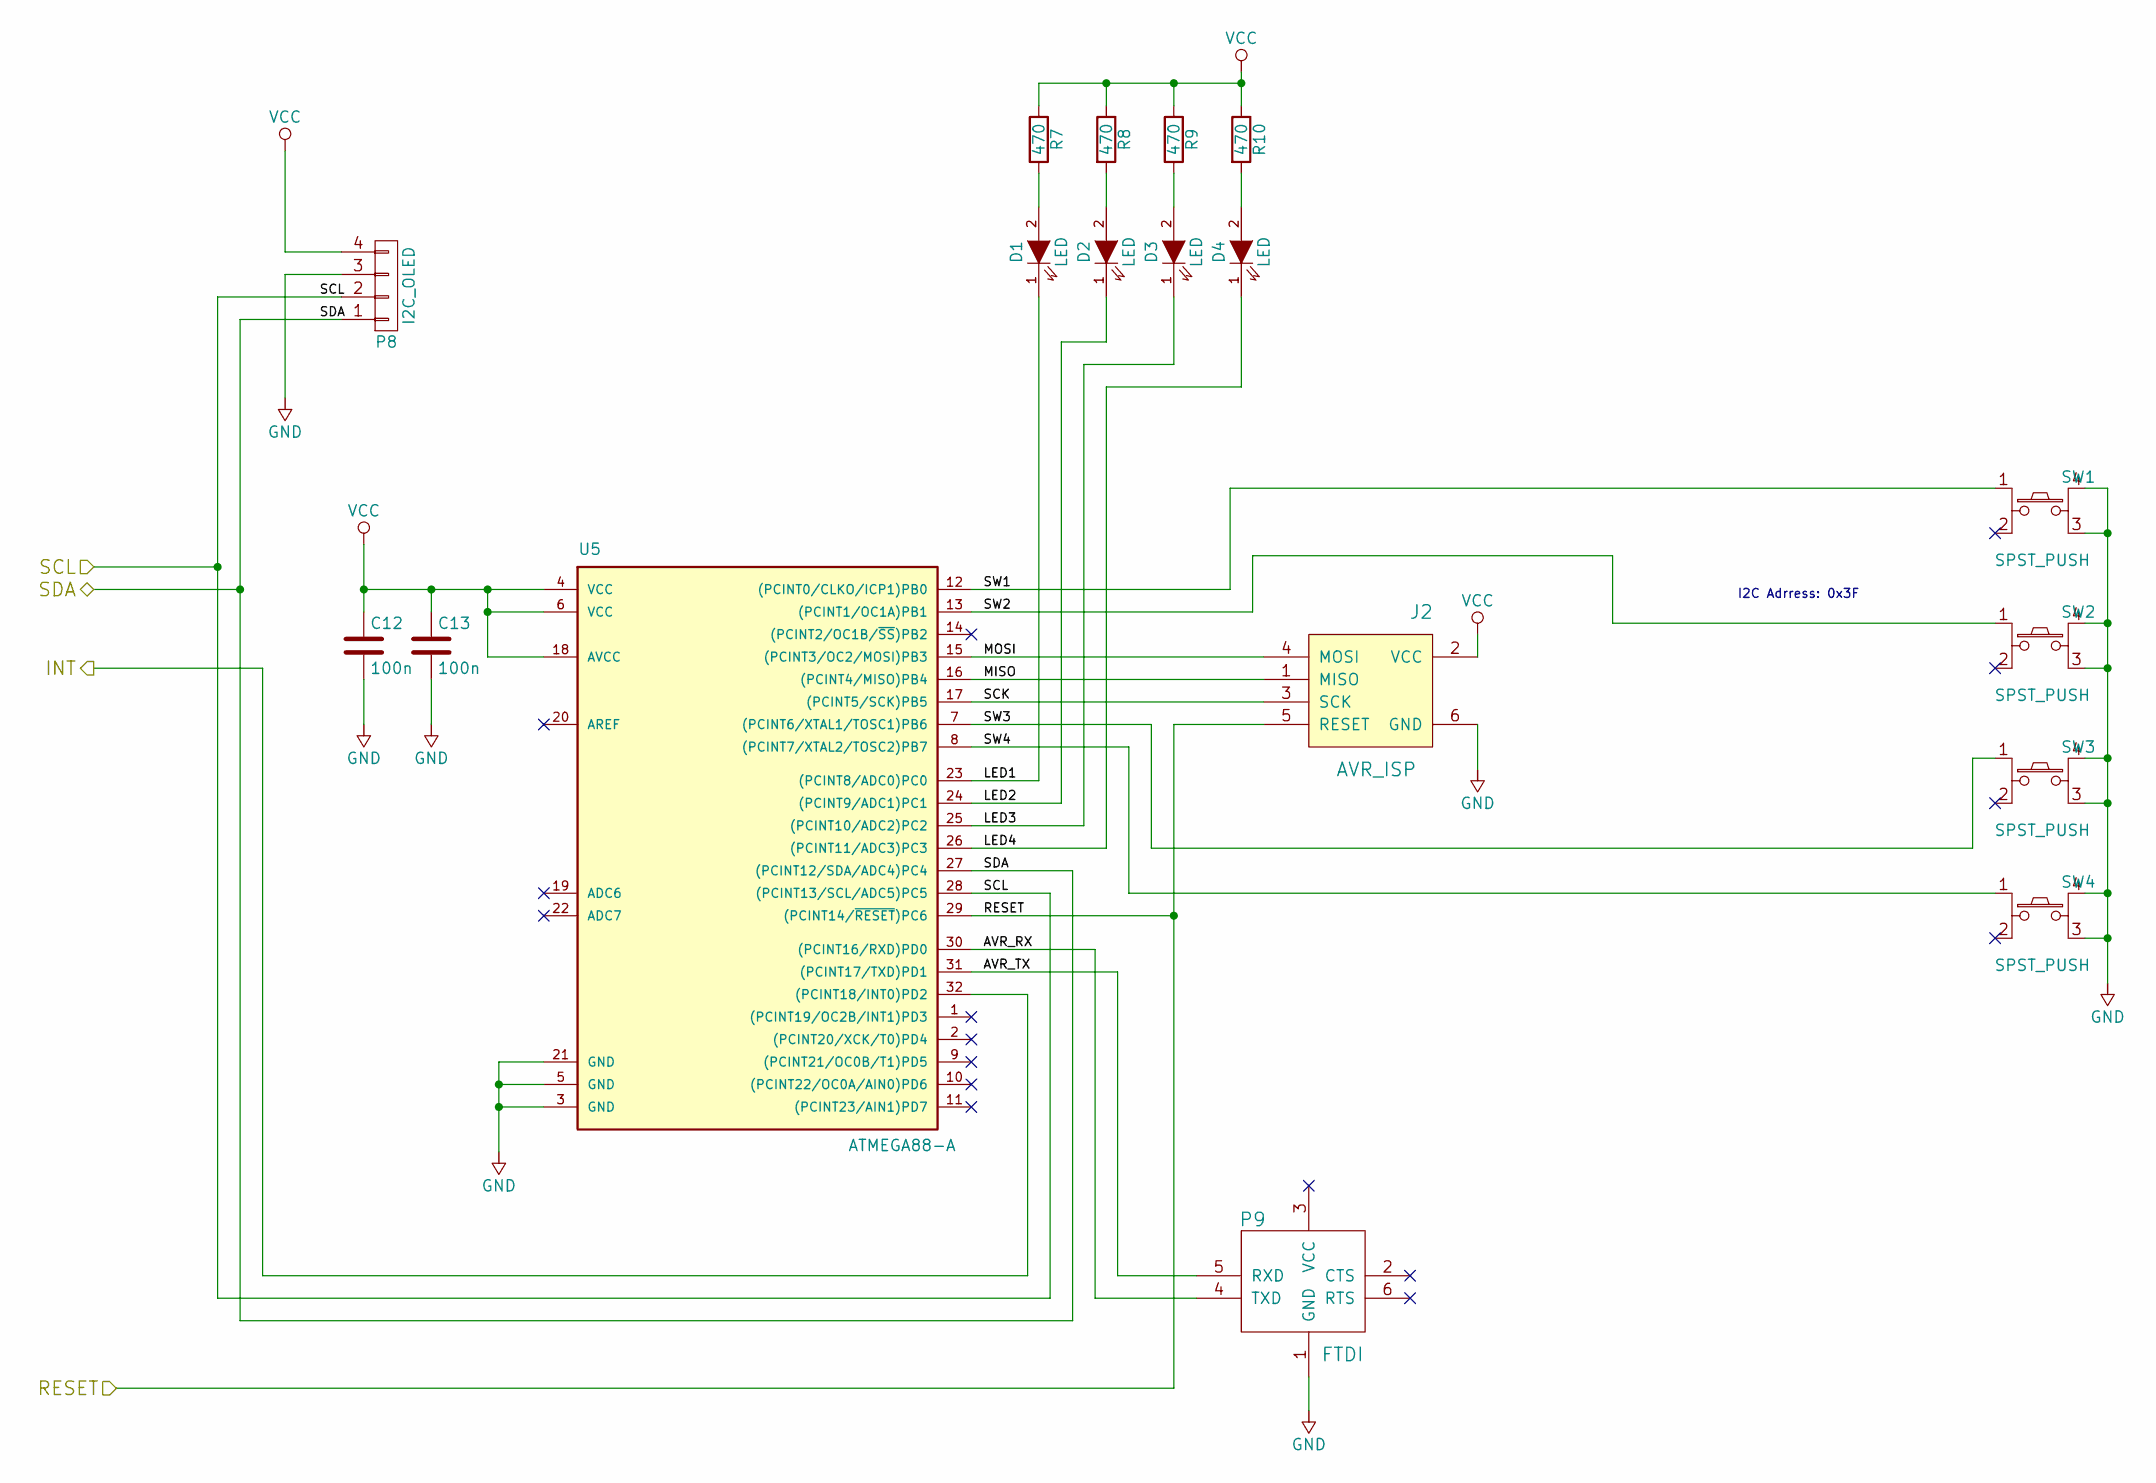
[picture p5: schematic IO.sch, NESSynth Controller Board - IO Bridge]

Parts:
C12, C13: 100n; C_0805_HandSoldering
D1, D2, D3, D4: LED; LED_0805
J2: AVR_ISP; AVR_ISP_SMALL
P8: I2C_OLED; LCD_I2C_96
P9: FTDI; Pin_Header_Straight_1x06
R7, R8, R9, R10: 470; R_0805_HandSoldering
SW1, SW2, SW3, SW4: SPST_PUSH; SW_PUSH_SMALL_4
U5: ATMEGA88-A; TQFP-32_7x7mm_Pitch0.8mm

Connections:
/IO/AVR_RX: P9.4 (TXD), U5.30 ((PCINT16/RXD)PD0)
/IO/AVR_TX: P9.5 (RXD), U5.31 ((PCINT17/TXD)PD1)
/IO/INT: U5.32 ((PCINT18/INT0)PD2); also elsewhere on the board
/IO/LED1: D1.1 (K), U5.23 ((PCINT8/ADC0)PC0)
/IO/LED2: D2.1 (K), U5.24 ((PCINT9/ADC1)PC1)
/IO/LED3: D3.1 (K), U5.25 ((PCINT10/ADC2)PC2)
/IO/LED4: D4.1 (K), U5.26 ((PCINT11/ADC3)PC3)
/IO/MISO: J2.1 (MISO), U5.16 ((PCINT4/MISO)PB4)
/IO/MOSI: J2.4 (MOSI), U5.15 ((PCINT3/OC2/MOSI)PB3)
/IO/RESET: J2.5 (RESET), U5.29 ((PCINT14/~RESET~)PC6); also elsewhere on the board
/IO/SCK: J2.3 (SCK), U5.17 ((PCINT5/SCK)PB5)
/IO/SCL: P8.2, U5.28 ((PCINT13/SCL/ADC5)PC5); also elsewhere on the board
/IO/SDA: P8.1, U5.27 ((PCINT12/SDA/ADC4)PC4); also elsewhere on the board
/IO/SW1: SW1.1 (A1), U5.12 ((PCINT0/CLKO/ICP1)PB0)
/IO/SW2: SW2.1 (A1), U5.13 ((PCINT1/OC1A)PB1)
/IO/SW3: SW3.1 (A1), U5.7 ((PCINT6/XTAL1/TOSC1)PB6)
/IO/SW4: SW4.1 (A1), U5.8 ((PCINT7/XTAL2/TOSC2)PB7)
GND: C12.2, C13.2, J2.6 (GND), P8.3, P9.1 (GND), SW1.3 (B2), SW1.4 (B1), SW2.3 (B2), SW2.4 (B1), SW3.3 (B2), SW3.4 (B1), SW4.3 (B2), SW4.4 (B1), U5.3 (GND), U5.5 (GND), U5.21 (GND); also elsewhere on the board
unnamed: D1.2 (A), R7.2
unnamed: D2.2 (A), R8.2
unnamed: D3.2 (A), R9.2
unnamed: D4.2 (A), R10.2
VCC: C12.1, C13.1, J2.2 (VCC), P8.4, R7.1, R8.1, R9.1, R10.1, U5.4 (VCC), U5.6 (VCC), U5.18 (AVCC); also elsewhere on the board

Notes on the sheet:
I2C Adrress: 0x3F

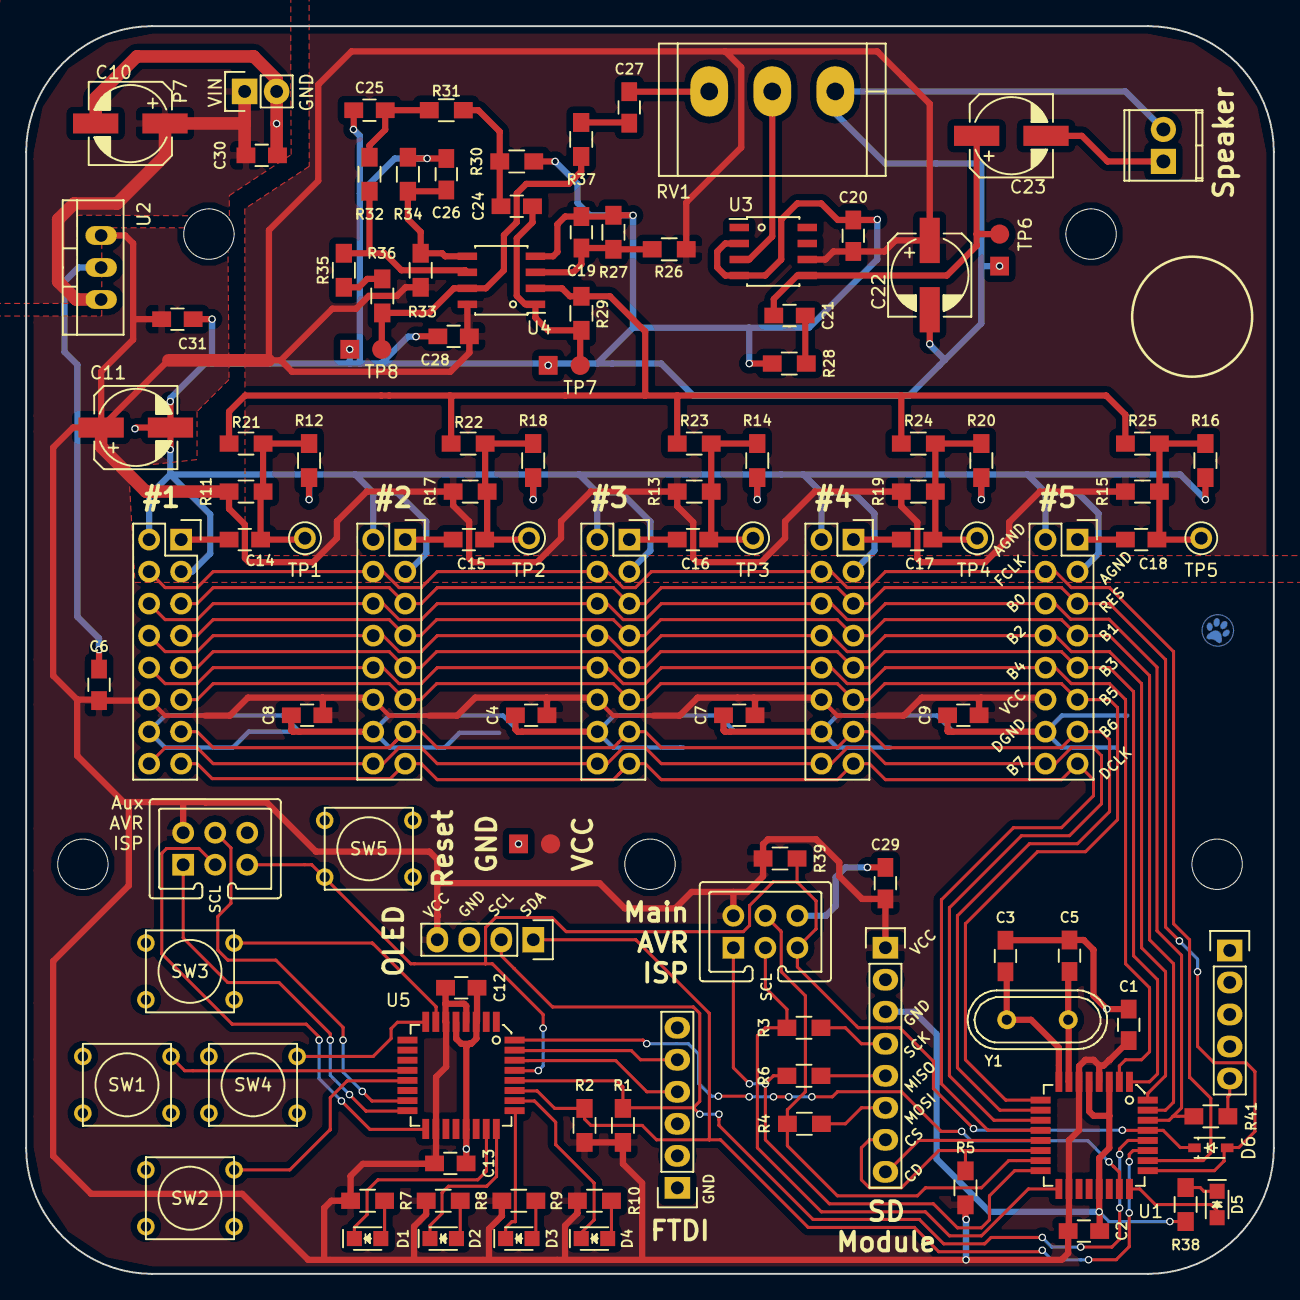
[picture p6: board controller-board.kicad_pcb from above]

Board: 2 copper layers, 99.0 x 99.0 mm, 120 parts (0 on the bottom side), 73 nets.

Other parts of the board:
MH1, MH2, MH3, MH4, MH5: MOUNTING_HOLE; MountingHole_4mm

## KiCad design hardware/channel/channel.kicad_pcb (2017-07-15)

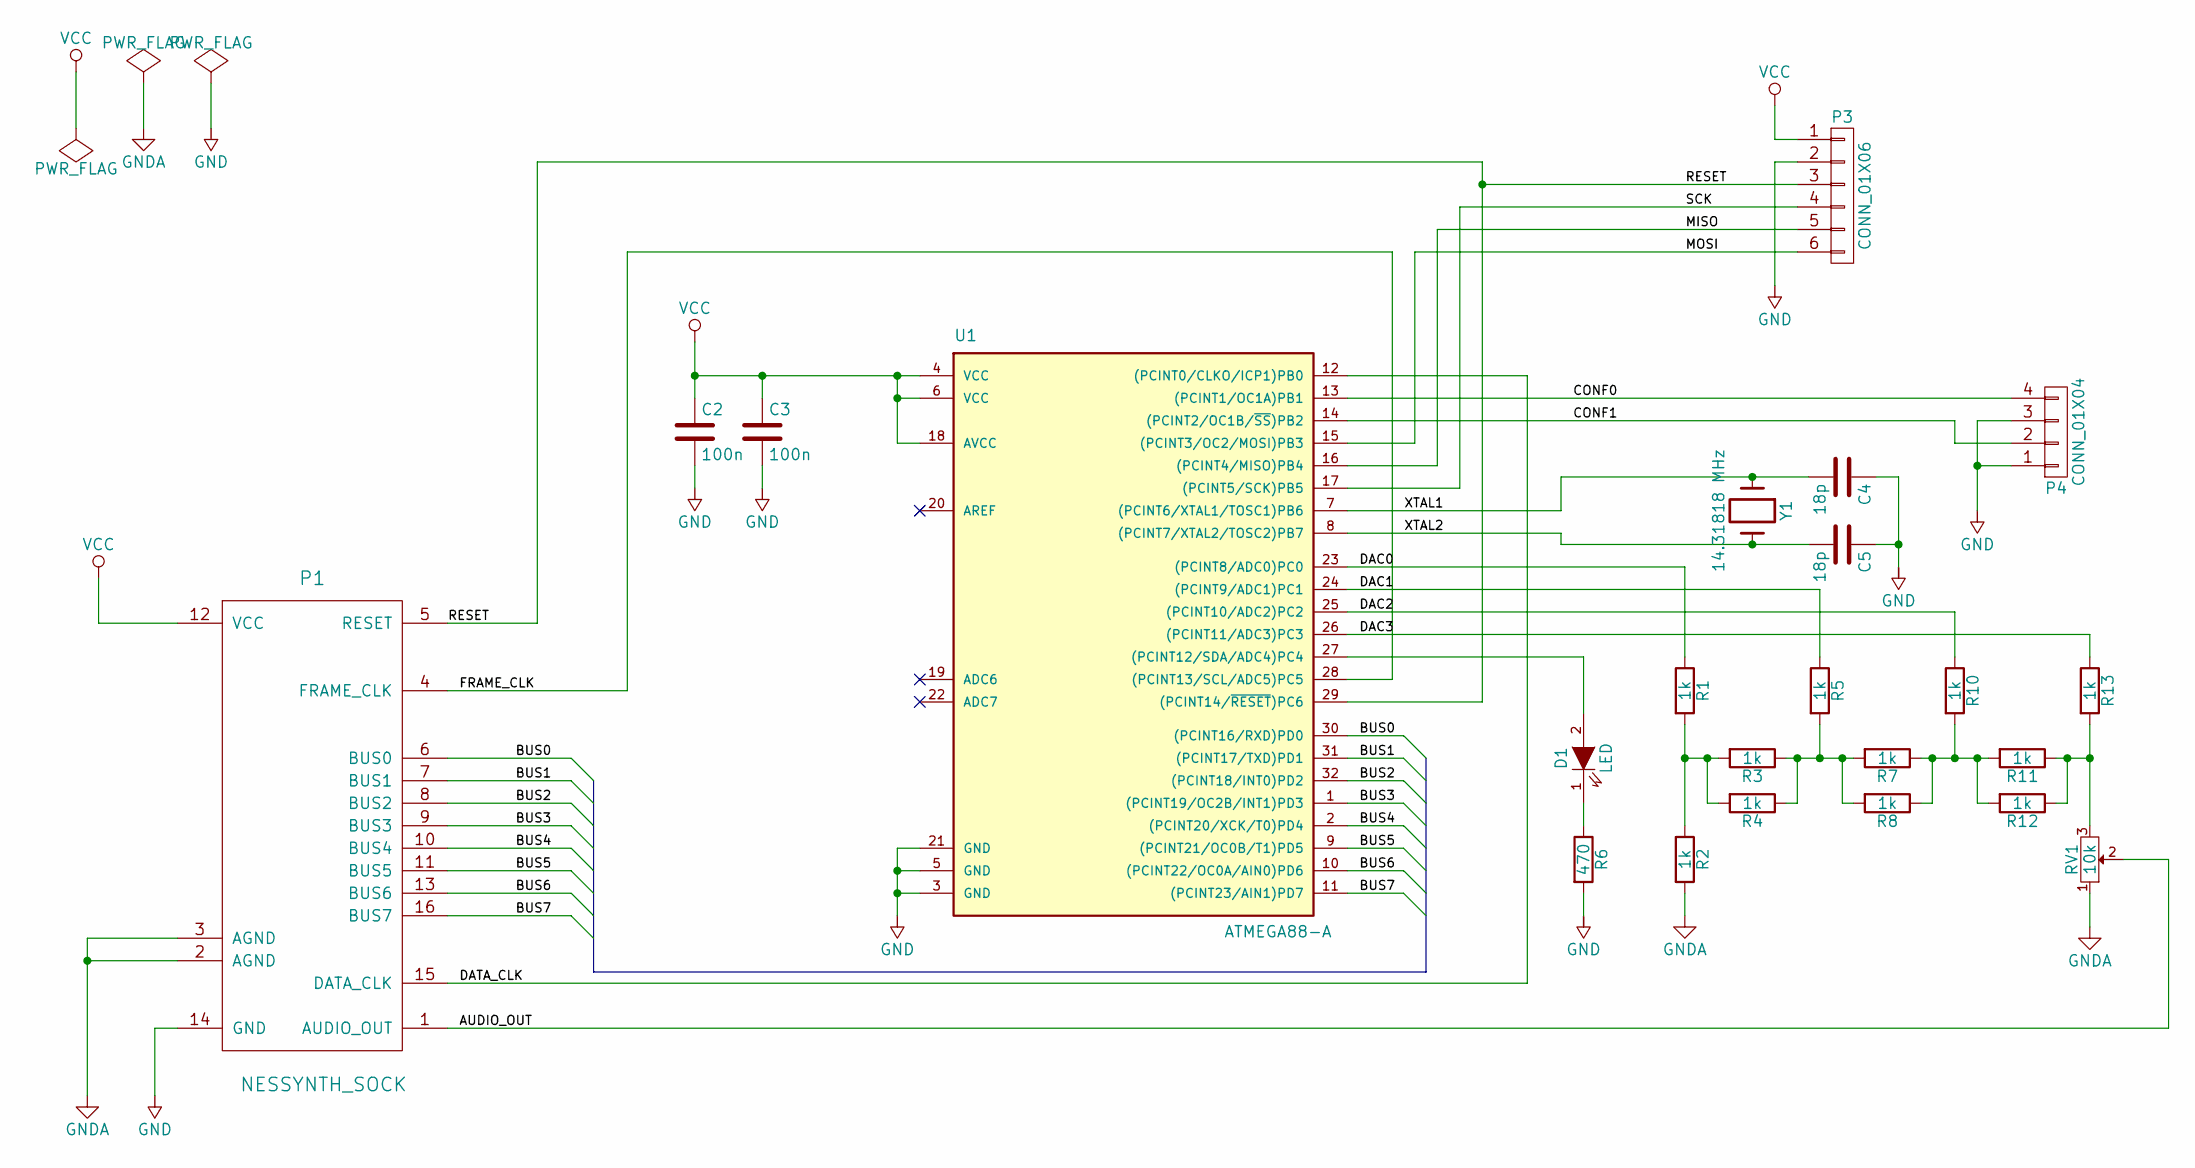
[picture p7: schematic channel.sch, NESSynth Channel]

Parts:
C2, C3: 100n; C_0805_HandSoldering
C4, C5: 18p; C_0805_HandSoldering
D1: LED; LED_0805
P1: NESSYNTH_SOCK; Pin_Header_Straight_2x08
P3: CONN_01X06; Pin_Header_Straight_1x06
P4: CONN_01X04; Pin_Header_Straight_1x04
R1, R2, R3, R4, R5, R7, R8, R10, R11, R12, R13: 1k; R_0805_HandSoldering
R6: 470; R_0805_HandSoldering
RV1: 10k; Potentiometer_Bourns_3386P
U1: ATMEGA88-A; TQFP-32_7x7mm_Pitch0.8mm
Y1: 14.31818 MHz; Crystal_HC49-U_Vertical

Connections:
/AUDIO_OUT: P1.1 (AUDIO_OUT), RV1.2
/BUS0: P1.6 (BUS0), U1.30 ((PCINT16/RXD)PD0)
/BUS1: P1.7 (BUS1), U1.31 ((PCINT17/TXD)PD1)
/BUS2: P1.8 (BUS2), U1.32 ((PCINT18/INT0)PD2)
/BUS3: P1.9 (BUS3), U1.1 ((PCINT19/OC2B/INT1)PD3)
/BUS4: P1.10 (BUS4), U1.2 ((PCINT20/XCK/T0)PD4)
/BUS5: P1.11 (BUS5), U1.9 ((PCINT21/OC0B/T1)PD5)
/BUS6: P1.13 (BUS6), U1.10 ((PCINT22/OC0A/AIN0)PD6)
/BUS7: P1.16 (BUS7), U1.11 ((PCINT23/AIN1)PD7)
/CONF0: P4.4, U1.13 ((PCINT1/OC1A)PB1)
/CONF1: P4.2, U1.14 ((PCINT2/OC1B/~SS~)PB2)
/DAC0: R1.1, U1.23 ((PCINT8/ADC0)PC0)
/DAC1: R5.1, U1.24 ((PCINT9/ADC1)PC1)
/DAC2: R10.1, U1.25 ((PCINT10/ADC2)PC2)
/DAC3: R13.1, U1.26 ((PCINT11/ADC3)PC3)
/DATA_CLK: P1.15 (DATA_CLK), U1.12 ((PCINT0/CLKO/ICP1)PB0)
/FRAME_CLK: P1.4 (FRAME_CLK), U1.28 ((PCINT13/SCL/ADC5)PC5)
/MISO: P3.5, U1.16 ((PCINT4/MISO)PB4)
/MOSI: P3.6, U1.15 ((PCINT3/OC2/MOSI)PB3)
/RESET: P1.5 (RESET), P3.3, U1.29 ((PCINT14/~RESET~)PC6)
/SCK: P3.4, U1.17 ((PCINT5/SCK)PB5)
/XTAL1: C4.2, U1.7 ((PCINT6/XTAL1/TOSC1)PB6), Y1.1
/XTAL2: C5.2, U1.8 ((PCINT7/XTAL2/TOSC2)PB7), Y1.2
GND: C2.2, C3.2, C4.1, C5.1, P1.14 (GND), P3.2, P4.1, P4.3, R6.2, U1.3 (GND), U1.5 (GND), U1.21 (GND)
GNDA: P1.2 (AGND), P1.3 (AGND), R2.2, RV1.1
unnamed: D1.1 (K), R6.1
unnamed: D1.2 (A), U1.27 ((PCINT12/SDA/ADC4)PC4)
unnamed: R1.2, R2.1, R3.2, R4.2
unnamed: R3.1, R4.1, R5.2, R7.2, R8.2
unnamed: R7.1, R8.1, R10.2, R11.2, R12.2
unnamed: R11.1, R12.1, R13.2, RV1.3
VCC: C2.1, C3.1, P1.12 (VCC), P3.1, U1.4 (VCC), U1.6 (VCC), U1.18 (AVCC)

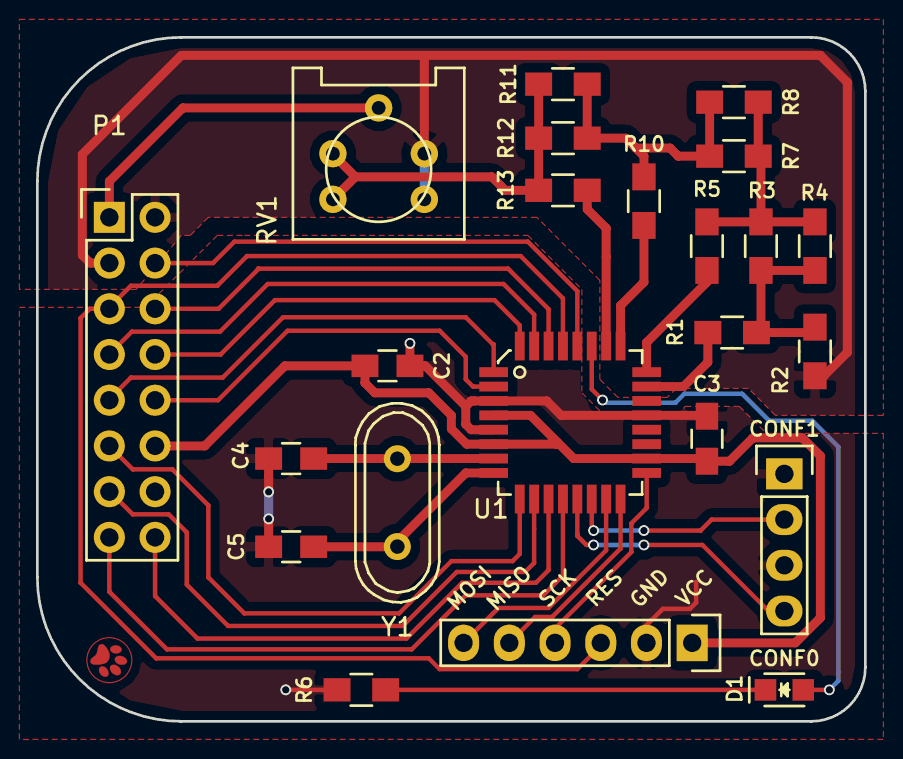
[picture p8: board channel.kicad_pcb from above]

Board: 2 copper layers, 46.0 x 38.0 mm, 23 parts (0 on the bottom side), 32 nets.

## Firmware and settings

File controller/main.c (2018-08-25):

/************************************************************************
 * Main controller
 *
 * The main playing loop reads data from the SD card into two circular
 * buffer (one with addresses and one with data values), and handles
 * user input
 *
 * Playback is performed using two timers:
 *
 * - Timer 0 fires at 240 Hz
 *   and outputs the frame clock. At every four frames it starts timer 2
 *   to output data
 *
 * - Timer 1 fires at 8 Hz and increments global_timer
 *
 * - Timer 2 fires at around 60 kHz. It outputs the data from the address
 *   and value buffers to the bus, and stops itself once it finds the end
 *   of frame marker
 ************************************************************************/


#include <avr/io.h>
#include <avr/pgmspace.h>
#include <util/delay.h>
#include <avr/interrupt.h>
#include <avr/eeprom.h>

#include <stdlib.h>

#include "config.h"
#include "io.h"

#include "i2c-master.h"
#include "ssd1306.h"
#include "sd.h"
#include "fat32.h"
#include "log.h"
#include "io-bridge.h"
#include "menu.h"
#include "cbuf.h"

#include "ssd1306-internal.h"
#include "ssd1306-cmd.h"
#include "logo-paw-64x64.h"
#include "logo-paw-48x48.h"
#include <string.h>

#define reg_address_LEN 128
#define reg_data_LEN 128

struct
{
    volatile uint8_t head;
    volatile uint8_t tail;
    volatile uint8_t buf[reg_address_LEN];
} reg_address;

struct
{
    volatile uint8_t head;
    volatile uint8_t tail;
    volatile uint8_t buf[reg_data_LEN];
} reg_data;

////////////////////////////////////////////////////////////////////////////////

uint16_t global_timer;

static inline void channel_reset_hold();
static inline void channel_reset_release();

void io_init();
void spi_init();
void timers_init();

static inline void timer0_start();
static inline void timer0_stop();
static inline void timer2_start();
static inline void timer2_stop();

void error_led_loop();

void i2c_scan();

void clear_inputs();
uint8_t get_input();


////////////////////////////////////////////////////////////////////////////////

void bitmap(const char* filename);

////////////////////////////////////////////////////////////////////////////////

volatile uint8_t song_done;

void reset_channels();
uint8_t song_play(const char* filename);
uint8_t song_handle_inputs();

void song_open(const char* filename);
void song_stop();

void song_read_data();

#define SONG_STOP 0x01
#define SONG_NEXT 0x02
#define SONG_PREV 0x04

////////////////////////////////////////////////////////////////////////////////

#define XSTR(s) STR(s)
#define STR(s) #s

static const char title_str[] PROGMEM = "NESSynth " XSTR(MAJOR_VERSION) "." XSTR(MINOR_VERSION);
static const uint8_t copyright_c[] PROGMEM = { 0x3C, 0x42, 0x99, 0xA5, 0xA5, 0x81, 0x42, 0x3C };
static const char copyright[] PROGMEM = COPYRIGHT_YEAR " " AUTHOR;

static const char menu_name_cat[8] PROGMEM = "CAT";

static const char menu_main_entry_0[] PROGMEM = "Songs sorted by game";
static const char menu_main_entry_1[] PROGMEM = "Play playlist";
static const char menu_main_entry_2[] PROGMEM = "Edit playlist";
static const char menu_main_entry_3[] PROGMEM = "Log";
static const char menu_main_entry_4[] PROGMEM = "About";

#define MENU_MAIN_SONGS_SORTED_BY_GAME 0
#define MENU_MAIN_PLAY_PLAYLIST 1
#define MENU_MAIN_EDIT_PLAYLIST 2
#define MENU_MAIN_LOG 3
#define MENU_MAIN_ABOUT 4

static const char* const menu_main_entries[] PROGMEM = {
    menu_main_entry_0,
    menu_main_entry_1,
    menu_main_entry_2,
    menu_main_entry_3,
    menu_main_entry_4,
};

static const char menu_playlist_edit_entry_0[] PROGMEM = "Add Track";
static const char menu_playlist_edit_entry_1[] PROGMEM = "Delete Track";
static const char menu_playlist_edit_entry_2[] PROGMEM = "Reorder Tracks";

#define MENU_PLAYLIST_EDIT_ADD_TRACK 0
#define MENU_PLAYLIST_EDIT_DELETE_TRACK 1
#define MENU_PLAYLIST_EDIT_REORDER_TRACKS 2

static const char* const menu_playlist_edit_entries[] PROGMEM = {
    menu_playlist_edit_entry_0,
    menu_playlist_edit_entry_1,
    menu_playlist_edit_entry_2
};


struct menu_info_t menu_main_info;
struct menu_info_t menu_game_info;
struct menu_info_t menu_playlist_info;
struct menu_info_t menu_playlist_edit_info;


////////////////////////////////////////////////////////////////////////////////

static inline void channel_reset_hold()
{
    disable_pullup(PIN_CH_RESET);
    set_output(PIN_CH_RESET);
    set_low(PIN_CH_RESET);
}

static inline void channel_reset_release()
{
    set_input(PIN_CH_RESET);
    enable_pullup(PIN_CH_RESET);
}


void io_init()
{
    set_outputs(PINS_BUS);
    set_output(PIN_DCLK);
    set_output(PIN_FCLK);

    set_low(PIN_DCLK);
    set_low(PIN_FCLK);

    set_output(PIN_MOSI);
    set_input(PIN_MISO);
    set_output(PIN_SCK);
    set_output(PIN_SD_CS);

    set_high(PIN_SD_CS);

    set_input(PIN_SD_CD);
    enable_pullup(PIN_SD_CD);

    set_input(PIN_IO_INT);
    set_output(PIN_LED);
}

void spi_init()
{
  // Enable SPI as master, MSB first, clock rate f_osc/16
    SPCR |= _BV(MSTR) | _BV(SPE) |  (0 << SPR1) | (1 << SPR0);

  // Clear double speed
  SPSR &= ~(1 << SPI2X);

  log_puts_P(PSTR("SPI initialised\n"));
}



void i2c_scan()
{
    log_puts("Scanning for I2C devices\n");

    uint8_t num = 0;

    for(uint8_t address = 0; address < 0x80; address++)
    {
        uint8_t status = i2c_start(address, I2C_WRITE);

        if(status == I2C_OK)
        {
            i2c_stop();

            log_puts("Device found at 0x");
            log_put_uint8_hex(address);
            log_nl();

            num++;
        }
    }

    if(!num)
    {
        log_puts("No devices found\n");
    }
}



void bitmap(const char* filename)
{
    log_puts("Opening \"");
    log_puts(filename);
    log_puts("\"\n");

    fat32_open_root_dir();
    fat32_open_file(filename, "BIT");

    uint8_t buf[128];

    ssd1306_bitmap_begin();

    while(fat32_read(&buf, 128))
    {
        for(uint8_t j = 0; j < 16; j++)
        {
            for(uint8_t i = 0; i < 8; i++)
            {
                uint8_t b0 = (buf[j +   0] & _BV(7-i)) ? 1 : 0;
                uint8_t b1 = (buf[j +  16] & _BV(7-i)) ? 1 : 0;
                uint8_t b2 = (buf[j +  32] & _BV(7-i)) ? 1 : 0;
                uint8_t b3 = (buf[j +  48] & _BV(7-i)) ? 1 : 0;
                uint8_t b4 = (buf[j +  64] & _BV(7-i)) ? 1 : 0;
                uint8_t b5 = (buf[j +  80] & _BV(7-i)) ? 1 : 0;
                uint8_t b6 = (buf[j +  96] & _BV(7-i)) ? 1 : 0;
                uint8_t b7 = (buf[j + 112] & _BV(7-i)) ? 1 : 0;

                i2c_write_byte((b7 << 7) | (b6 << 6) | (b5 << 5) | (b4 << 4) | (b3 << 3) | (b2 << 2) | (b1 << 1) | (b0 << 0));
            }
        }
        _delay_ms(1);
    }
    ssd1306_bitmap_end();
    fat32_close_file();
}


static inline void timer0_start()
{
    TCCR0B |= _BV(CS02); // Prescaler 256
}

static inline void timer0_stop()
{
    TCCR0B &= ~_BV(CS02);
}

static inline void timer2_start()
{
    TCCR2B |= _BV(CS21); // Prescaler 8
}

static inline void timer2_stop()
{
    TCCR2B &= ~_BV(CS21);
}

void timers_init()
{
    TCCR0A = _BV(WGM01); // CTC mode
    TCCR0B = 0;
    TIMSK0 |= _BV(OCIE0A); // Set interrupt on compare match
    OCR0A = 232; // 14318180 Hz / 256 / (232 + 1) = 240 Hz

    TCCR1A = 0;
    TCCR1B = _BV(WGM12) | _BV(CS12) | _BV(CS10); // CTC mode, prescaler 1024
    TIMSK1 |= _BV(OCIE1A);
    OCR1A = 1747; // 8 Hz timer

    TCCR2A = _BV(WGM21); // CTC mode
    TCCR2B = 0;
    TIMSK2 |= _BV(OCIE2A); // Set interrupt on compare match
    OCR2A = 59; // Interrupt every ~ 33 us
}

void song_open(const char* filename)
{
    fat32_open_root_dir();

    if(fat32_open_file(filename, "BIN"))
    {
        song_done = 0;

        log_puts("Playing \"");
        log_puts(filename);
        log_puts("\"\n");

        timer0_start();
    } else {
        log_puts("Could not open file \"");
        log_puts(filename);
        log_puts("\"\n");

        error_led_loop();
    }
}

void song_stop()
{
    timer0_stop();
    fat32_close_file();
}


void error_led_loop()
{
    for(;;)
    {
        set_high(PIN_LED);
        _delay_ms(125);
        set_low(PIN_LED);
        _delay_ms(125);

        set_high(PIN_LED);
        _delay_ms(125);
        set_low(PIN_LED);
        _delay_ms(125);

        set_high(PIN_LED);
        _delay_ms(125);
        set_low(PIN_LED);

        _delay_ms(375);
    }
}

void song_read_data()
{
    while(!cbuf_full(reg_data))
    {
        uint8_t data[2];

        fat32_read(data, 2); // TODO: read more than two bytes at a time!

        if(cbuf_empty(reg_data))
        {
            set_high(PIN_LED);
        }


        if(data[0] == 0xFE)
        {
            fat32_read(data, 2); // TODO: read more than two bytes at a time!
            uint16_t dest = ((uint16_t)data[0]<<8) | data[1];
            log_puts("Loop to 0x");
            log_put_uint16_hex(dest);
            log_puts("\n");


            toggle(PIN_LED);

            fat32_seek(dest);
        } else {
            cbuf_push(reg_address, data[0]);
            cbuf_push(reg_data, data[1]);
        }
    }
}

void reset_channels()
{
    cli();
    cbuf_init(reg_address);
    cbuf_init(reg_data);

    for(uint8_t n = 0; n <= 0x17; n++)
    {
        cbuf_push(reg_address, n);
        cbuf_push(reg_data, 0);
    }

    sei();

    timer2_start();
}

// maximum play time for each song in units of 1/8 s
#define MAX_PLAY_TIME (8 * 60 * 3)

uint8_t song_play(const char* filename)
{
    uint16_t start_time = global_timer;

    song_open(filename);
    song_read_data();
    set_low(PIN_LED);

    uint8_t ret;

    while(!(ret = song_handle_inputs()) && !song_done)
    {
        song_read_data();

        if(global_timer - start_time > MAX_PLAY_TIME)
        {
            song_done = 1  ;
        }
    }

    reset_channels();
    _delay_ms(100); // Make sure channels have time to stop playing
    song_stop();

    if(!ret)
    {
        ret = SONG_NEXT;
    }

    return ret;
}

void clear_inputs()
{
    // Why is this needed???
    i2c_start(I2C_IO_BRIDGE_ADDRESS, I2C_WRITE);
    i2c_stop();

    i2c_start(I2C_IO_BRIDGE_ADDRESS, I2C_READ);
    i2c_read_nak();
    i2c_stop();
}

uint8_t song_handle_inputs()
{
    uint8_t action = 0;
    switch(get_input())
    {
    case BUTTON_PRESS_LEFT:
        action = SONG_PREV;
        break;

    case BUTTON_PRESS_RIGHT:
        action = SONG_NEXT;
        break;

    case BUTTON_PRESS_UP:
    case BUTTON_PRESS_DOWN:
        action = SONG_STOP;
        break;
    }
    return action;
}


void category_read_info(uint8_t choice, char *catname, uint8_t *len)
{
    fat32_open_root_dir();
    fat32_open_file("CAT", MENU_EXT);

    fat32_seek(0);

    fat32_skip_until('\n'); // Skip number of lines + new line
    for(uint8_t i = 0; i < choice; i++)
    {
        fat32_skip_until('\n');
    }

    ssd1306_text_start(0,1);

    char c;
    for(uint8_t i = 0; i < 20; i++)
    {
        fat32_read(&c, 1);
        ssd1306_text_putc(c);
    }
    ssd1306_text_end();

    fat32_read(catname, 6);

    char numstr[3];
    fat32_read(numstr, 3);

    *len = (numstr[1]-'0')*10 + (numstr[2]-'0');

    fat32_close_file();
}


void category_play(uint8_t choice)
{
    ssd1306_clear();
    ssd1306_puts("Playing:",0,0);

    char filename[9];
    uint8_t len;

    category_read_info(choice, filename, &len);

    uint8_t done = 0;
    int8_t num = 1;

    while(!done)
    {
        filename[6] = '0' + (num / 10);
        filename[7] = '0' + (num % 10);
        filename[8] = 0;

        char track[] = "Track 67/9A";


        if(len < 10)
        {
            track[6] = '0' + num;
            track[7] = '/';
            track[8] = '0' + len;
            track[9] = ' ';
            track[10] = ' ';
        } else {
            if(num < 10)
            {
                track[6] = ' ';
            } else {
                track[6] = '0' + (num/10);
            }
            track[7] = '0' + (num%10);

            track[9] = '0' + (len/10);
            track[10] = '0' + (len%10);
        }

        ssd1306_puts(track, 0, 2);


        uint8_t ret = song_play(filename);

        switch(ret)
        {
        case SONG_NEXT:
            num++;
            if(num > len)
            {
                num = 1;
            }
            break;

        case SONG_PREV:
            num--;
            if(num <= 0)
            {
                num = len;
            }
            break;

        case SONG_STOP:
            done = 1;
            break;
        }
    }
}

void about_show()
{
    ssd1306_clear();

    ssd1306_puts_P(title_str,12,0);

    ssd1306_text_start(0,7);
    i2c_write_P(copyright_c, 8);
    ssd1306_text_end();

    ssd1306_puts_P(copyright, 12,7);

    while(!get_input())
        ;
}

void splash_show()
{
}

extern char log_buf[LOG_BUF_LEN];

void log_show()
{
    uint8_t num_lines = log_buf_count_lines();
    uint8_t first_line = num_lines - 8;
    uint8_t done = 0;

    // TODO: Don't redraw everything each time. Instead use the scrolling capabilities of SSD1306

    while(!done)
    {
        ssd1306_clear();

        for(uint8_t i = 0; i < 8; i++)
        {

            uint8_t pos = log_buf_line_pos(first_line + i);

            for(uint8_t j = 0; j < LOG_BUF_LINE_WIDTH; j++)
            {
                char c = log_buf[(uint8_t)(pos + j)];
                if(c == '\n')
                    break;

                ssd1306_putc(c, 6*j, i);
            }
        }

        uint8_t input;

        while(!(input = get_input()))
            ;

        switch(input)
        {
        case BUTTON_PRESS_LEFT:
        case BUTTON_PRESS_RIGHT:
            done = 1;
        break;

        case BUTTON_PRESS_UP:
        case BUTTON_HOLD_UP:
        if(first_line > 0)
        {
            first_line--;
        }
        break;

        case BUTTON_PRESS_DOWN:
        case BUTTON_HOLD_DOWN:
        if(first_line < num_lines - 8)
        {
            first_line++;
        }
        break;

        }
    }
}

static void menu_init()
{
    menu_pgm_init(menu_main_entries, sizeof(menu_main_entries)/sizeof(menu_main_entries[0]), &menu_main_info);
    menu_pgm_init(menu_playlist_edit_entries, sizeof(menu_playlist_edit_entries)/sizeof(menu_playlist_edit_entries[0]), &menu_playlist_edit_info);
    menu_fat32_init(menu_name_cat, &menu_game_info);
    menu_eeprom_init(&menu_playlist_info);
}


static void menu_play_category_loop()
{
    for(;;)
    {
        uint8_t res = menu_loop(&menu_game_info);
        if(res & MENU_BACK_FLAG)
                    break;

        category_play(res);
    }
}

static void menu_play_playlist_loop()
{
    for(;;)
    {
        uint8_t res = menu_loop(&menu_playlist_info);
        if(res & MENU_BACK_FLAG)
            break;

        char filename[8];
        eeprom_read_block(filename, (void*)(res*8), 8);

        song_play(filename);
    }
}

static void menu_edit_playlist_loop()
{
    for(;;)
    {
        uint8_t res = menu_loop(&menu_playlist_edit_info);
        if(res & MENU_BACK_FLAG)
            break;

        switch(res)
        {
        case MENU_PLAYLIST_EDIT_ADD_TRACK:
            for(;;)
            {
                res = menu_loop(&menu_game_info);
                if(res & MENU_BACK_FLAG)
                    break;

                char filename[8];
                uint8_t len;

                category_read_info(res, filename, &len);

                uint8_t track = 1;

                ssd1306_clear();
                ssd1306_text_start(0,0);
                for(uint8_t i = 0; i < 8; i++)
                {
                    ssd1306_text_putc(filename[i]);
                }
                ssd1306_text_end();

                int8_t done = 0;

                while(!done)
                {
                    char tens = '0' + track / 10;
                    char ones = '0' + track % 10;

                    ssd1306_putc(tens, 6*6,0);
                    ssd1306_putc(ones, 7*6,0);

                    uint8_t input;
                    while(!(input = get_input()))
                        ;

                    switch(input)
                    {
                    case BUTTON_PRESS_UP:
                    case BUTTON_HOLD_UP:
                        if(track > 1)
                            track--;
                        break;

                    case BUTTON_PRESS_DOWN:
                    case BUTTON_HOLD_DOWN:
                        if(track < len)
                            track++;
                        break;

                    case BUTTON_PRESS_RIGHT:
                        done = 1;
                        break;

                    case BUTTON_PRESS_LEFT:
                        done = -1;
                        break;

                    }
                }

                if(done > 0) // Add track
                {
                    filename[6] = '0' + track / 10;
                    filename[7] = '0' + track % 10;
                    if(menu_playlist_info.num_items < 128)
                    {
                        eeprom_write_block(filename, (void*)(8 * menu_playlist_info.num_items), 8);
                        menu_playlist_info.num_items++;
                    }
                }
            }
            break;


        case MENU_PLAYLIST_EDIT_DELETE_TRACK:
            for(;;)
            {
                res = menu_loop(&menu_playlist_info);
                if(res & MENU_BACK_FLAG)
                    break;

                for(uint8_t i = res; i < menu_playlist_info.num_items; i++)
                {
                    uint8_t s[8];
                    eeprom_read_block(s,(void*)((i+1)*8),8);
                    eeprom_update_block(s,(void*)(i*8),8);
                }

                menu_playlist_info.num_items--;
            }
            break;

        case MENU_PLAYLIST_EDIT_REORDER_TRACKS:
            break;
        }
    }
}

int main()
{
    io_init();
    i2c_master_init();

    timers_init();

    cbuf_init(reg_address);
    cbuf_init(reg_data);

    sei();

    ssd1306_init();
//    ssd1306_splash();
    {
        ssd1306_clear();

        const struct ssd1306_frame_t frame = { .col_start = 0, .col_end = 63 , .row_start = 0, .row_end = 7, .offset = 0 };

        ssd1306_setup_frame(frame);

        i2c_start(OLED_I2C_ADDRESS, I2C_WRITE);
        i2c_write_byte(OLED_CONTROL_BYTE_DATA_STREAM);
        i2c_write_P(paw_64x64, (uint16_t)64 * 8);

        i2c_stop();

        ssd1306_puts("NESSynth",64+32-6*8/2,2);
        ssd1306_puts(XSTR(MAJOR_VERSION) "." XSTR(MINOR_VERSION),64+32-6*3/2,4);

//        ssd1306_clear();


        for(uint8_t i = 0; i < 60; i++)
        {
            ssd1306_puts_scroll("0123456789", 10, 1, 30, i);
            _delay_ms(125);
        }
    }
    _delay_ms(5000);

    log_init(LOG_I2C|LOG_BUF);
    spi_init();

    i2c_scan();

    if(is_high(PIN_SD_CD))
    {
        log_puts_P(PSTR("SD card detected\n"));
    } else {
        log_puts_P(PSTR("No SD card detected\n"));

        error_led_loop();
    }
    sd_init();
    fat32_init();

//    clear_inputs();

    menu_init();

    _delay_ms(1125);
    reset_channels();

    for(;;)
    {
        uint8_t res;

        res = menu_loop(&menu_main_info);

        switch(res)
        {
        case MENU_MAIN_SONGS_SORTED_BY_GAME:
            menu_play_category_loop();
            break;

        case MENU_MAIN_PLAY_PLAYLIST:
            menu_play_playlist_loop();
            break;

        case MENU_MAIN_EDIT_PLAYLIST:
            menu_edit_playlist_loop();
            break;

        case MENU_MAIN_LOG:
            log_show();
            break;

        case MENU_MAIN_ABOUT:
            about_show();
            break;


        default:
            ssd1306_splash();
            _delay_ms(500);
        }
    }
}

static uint8_t frame_counter;

ISR(TIMER0_COMPA_vect) // Frame clock fires at 240 Hz
{
    uint8_t cnt = frame_counter + 1;
    set_pin(PIN_FCLK, cnt & 1);

    if(!(cnt & 0x03))
    {
        // Push out new data at 60 Hz
        if(!song_done)
        {
            timer2_start();
        }
    }

    frame_counter = cnt;
}

ISR(TIMER1_COMPA_vect)
{
    global_timer++;
}

ISR(TIMER2_COMPA_vect) // Push out new data
{
    static uint8_t n = 0;

    if(cbuf_empty(reg_data))
    {
        timer2_stop(); // We are done for now
    } else {
        if(!(n++ & 0x01))
        {
            uint8_t address = cbuf_pop(reg_address);
            if(address == 0xFF) // End song
            {
                timer2_stop();
                cbuf_pop(reg_data);
                n++;
                song_done = 1;
            } else if(address == 0xF1) { // End frame
                timer2_stop();
                cbuf_pop(reg_data);
                n++;
            } else {
                PINS_BUS_PORT = address;
                set_high(PIN_DCLK);
            }
        } else {
            uint8_t value = cbuf_pop(reg_data);
            PINS_BUS_PORT = value;
            set_low(PIN_DCLK);
        }
    }
}

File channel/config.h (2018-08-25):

#ifndef CONFIG_H_
#define CONFIG_H_

// GPIOR0 bits

#define CONF0_BIT          0
#define CONF1_BIT          1
#define FRAME_FLAG_BIT     2
#define SHIFT_MODE_BIT     7

#ifdef AVR

// Audio out

#define PINS_DAC_PORT      PORTC
#define PINS_DAC_DDR       DDRC

#define PIN_DAC0           PORTC0
#define PIN_DAC1           PORTC1
#define PIN_DAC2           PORTC2
#define PIN_DAC3           PORTC3

#define PINS_DAC_MASK      (_BV(PIN_DAC0) | _BV(PIN_DAC1) | _BV(PIN_DAC2) | _BV(PIN_DAC3))


// Bus in

#define PINS_BUS_PORT      PORTD
#define PINS_BUS_PIN       PIND
#define PINS_BUS_DDR       DDRB

#define PIN_BUS0           PORTD0
#define PIN_BUS1           PORTD1
#define PIN_BUS2           PORTD2
#define PIN_BUS3           PORTD3
#define PIN_BUS4           PORTD4
#define PIN_BUS5           PORTD5
#define PIN_BUS6           PORTD6
#define PIN_BUS7           PORTD7

#define PINS_BUS_MASK      (_BV(PIN_BUS0) | _BV(PIN_BUS1) | _BV(PIN_BUS2) | _BV(PIN_BUS3) | _BV(PIN_BUS4) | _BV(PIN_BUS5) | _BV(PIN_BUS6) | _BV(PIN_BUS7))

// Bus clock

#define PIN_DCLK           PORTB0
#define PIN_DCLK_PORT      PORTB
#define PIN_DCLK_PIN       PINB
#define PIN_DCLK_DDR       DDRB

// Frame clock

#define PIN_FCLK           PORTC5
#define PIN_FCLK_PORT      PORTC
#define PIN_FCLK_PIN       PINC
#define PIN_FCLK_DDR       DDRC

// LED

#define PIN_LED           PORTC4
#define PIN_LED_PORT      PORTC
#define PIN_LED_PIN       PINC
#define PIN_LED_DDR       DDRC

// Config bits

#define PIN_CONF0           PORTB1
#define PIN_CONF0_PORT      PORTB
#define PIN_CONF0_PIN       PINB
#define PIN_CONF0_DDR       DDRB

#define PIN_CONF1           PORTB2
#define PIN_CONF1_PORT      PORTB
#define PIN_CONF1_PIN       PINB
#define PIN_CONF1_DDR       DDRB

#endif
#endif

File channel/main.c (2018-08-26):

#include <avr/io.h>
#include <util/delay.h>
#include <avr/interrupt.h>
#include <avr/sleep.h>


#include <stdlib.h>
#include <stddef.h>

#include "config.h"
#include "registers.h"

#include "io.h"

#include "cbuf.h"

#include "nes_apu_channel.h"

#define reg_address_LEN 32
#define reg_data_LEN 32

struct
{
    volatile uint8_t head;
    volatile uint8_t tail;
    volatile uint8_t buf[reg_address_LEN];
} reg_address;

struct
{
    volatile uint8_t head;
    volatile uint8_t tail;
    volatile uint8_t buf[reg_data_LEN];
} reg_data;


#if 0
volatile uint8_t frame_flag; // moved to GPIOR0
#endif


void (*write_reg)(uint8_t address, uint8_t val);
void (*frame_update)();


void io_init()
{
    set_outputs(PINS_DAC);

    set_inputs(PINS_BUS);
    disable_pullups(PINS_BUS);

    set_input(PIN_DCLK);
    disable_pullup(PIN_DCLK);

    set_input(PIN_FCLK);
    disable_pullup(PIN_FCLK);

    set_output(PIN_LED);

    set_input(PIN_CONF0);
    set_input(PIN_CONF1);

    enable_pullup(PIN_CONF0);
    enable_pullup(PIN_CONF1);
}

void timers_init()
{
    TCCR1A = 0;
    TCCR1B = _BV(WGM12);  // Mode 4, CTC on OCR1A
    TIMSK1 = _BV(OCIE1A); // Set interrupt on compare match
}

void interrupts_init()
{
    PCICR = _BV(PCIE1) | _BV(PCIE0); // Enable PCI0 and PCI1
    PCMSK0 = _BV(PCINT0);  // Enable DCLK interrupt
    PCMSK1 = _BV(PCINT13); // Enable FCLK interrupt
}

void read_conf()
{
    uint8_t conf = (is_high(PIN_CONF1) ? 2 : 0) | (is_high(PIN_CONF0) ? 1 : 0);

    channel_conf = (channel_conf & ~(_BV(CONF0_BIT) | _BV(CONF1_BIT))) | (is_high(PIN_CONF0) ? _BV(CONF0_BIT) : 0) | (is_high(PIN_CONF1) ? _BV(CONF1_BIT) : 0);

    switch(conf)
    {
    case CHAN_SQ1:
        write_reg = write_reg_sq1;
        frame_update = frame_update_sq;
        break;

    case CHAN_SQ2:
        write_reg = write_reg_sq2;
        frame_update = frame_update_sq;
        break;

    case CHAN_TRI:
        write_reg = write_reg_tri;
        frame_update = frame_update_tri;
        break;

    case CHAN_NOISE:
    default:
        write_reg = write_reg_noise;
        frame_update = frame_update_noise;

        channel_volume = 0;

        shift_register_hi = 0;
        shift_register_lo = 1;
        break;
    }
}

void blink_conf()
{
    uint8_t conf = (is_high(PIN_CONF1) ? 2 : 0) | (is_high(PIN_CONF0) ? 1 : 0);

    do
    {
        set_high(PIN_LED);
        _delay_ms(125);
        set_low(PIN_LED);
        _delay_ms(250);
    } while(conf--);
}

int main()
{
    io_init();
    timers_init();
    interrupts_init();

    cbuf_init(reg_address);
    cbuf_init(reg_data);

    read_conf();

    sei();

    blink_conf();

    for(;;)
    {
        while(!cbuf_empty(reg_data))
        {
            uint8_t address = cbuf_pop(reg_address);
            uint8_t val = cbuf_pop(reg_data);

            // TODO: Handle 0x4017 to change frame counter mode
            write_reg(address, val);
        }

        set_low(PIN_LED);

        if(frame_flag & _BV(FRAME_FLAG_BIT))
        {
            frame_flag &= ~_BV(FRAME_FLAG_BIT);
            frame_update();
        }
    }
}



#ifndef ASMINTERRUPT
ISR(TIMER1_COMPA_vect)
{
    set_high(PIN_LED);

    if(!(channel_conf & _BV(CONF1_BIT)))
    {
        // case CHAN_SQ1:
        // case CHAN_SQ2:

        channel_step = (channel_step+1) & 0x0F;

        if(channel_step < channel_duty_cycle)
        {
            PINS_DAC_PORT |= channel_volume;
        } else {
            PINS_DAC_PORT &= 0xF0;
        }
    } else {
        if(!(channel_conf & _BV(CONF0_BIT)))
        {
            // case CHAN_TRI:
            if((channel_linear_counter > 0) && (channel_length_counter > 0))
            {
                channel_step = (channel_step + 1) & 0x1F;

                uint8_t val = channel_step;

                if(channel_step & 0x10)
                {
                    val = ~channel_step;
                }

                PINS_DAC_PORT = (PINS_DAC_PORT & 0xF0) | (val & 0x0F);
            }
        } else {
            // case CHAN_NOISE:
            uint8_t feedback;

            if(channel_shift_mode & _BV(SHIFT_MODE_BIT))
            {
                feedback = ((shift_register_lo & _BV(0)) ^ ((shift_register_lo & _BV(6)) >> 6));
            } else {
                feedback = ((shift_register_lo & _BV(0)) ^ ((shift_register_lo & _BV(1)) >> 1));
            }

            // 16-bit shift right
            asm volatile(
                "lsr %0\t\n"
                "ror %1\t\n"
                : "=&r" (shift_register_hi), "=&r" (shift_register_lo):);

            if(feedback)
            {
                shift_register_hi |= 0x40;
            }

            if(!(shift_register_lo & _BV(0)))
            {
                PINS_DAC_PORT |= channel_volume;
            } else {
                PINS_DAC_PORT &= 0xF0;
            }
        }
    }

    set_low(PIN_LED);
}

ISR(PCINT1_vect)
{
    frame_flag |= _BV(FRAME_FLAG_BIT);
}

#endif

// High: address, Low: data

ISR(PCINT0_vect)
{
    if(is_high(PIN_DCLK))
    {
        cbuf_push(reg_address, PINS_BUS_PIN);
    } else {
        cbuf_push(reg_data, PINS_BUS_PIN);
    }
    set_high(PIN_LED);
}

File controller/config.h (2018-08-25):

#ifndef CONFIG_H_
#define CONFIG_H_

#include <avr/pgmspace.h>

#include "../common-config.h"

#define MAJOR_VERSION 0
#define MINOR_VERSION 1
#define COPYRIGHT_YEAR "2016-17"
#define AUTHOR "OOS"

#define BAUD 19200UL
#define SCL_CLOCK  100000UL

#define LOG_USE_I2C
#define LOG_USE_SSD1306
#define LOG_USE_BUF


//// Pins /////////////////////////////////////////////////////////////////////

// Bus out

#define PINS_BUS_PORT      PORTD
#define PINS_BUS_PIN       PIND
#define PINS_BUS_DDR       DDRD

#define PIN_BUS0           PORTD0
#define PIN_BUS1           PORTD1
#define PIN_BUS2           PORTD2
#define PIN_BUS3           PORTD3
#define PIN_BUS4           PORTD4
#define PIN_BUS5           PORTD5
#define PIN_BUS6           PORTD6
#define PIN_BUS7           PORTD7

#define PINS_BUS_MASK      (_BV(PIN_BUS0) | _BV(PIN_BUS1) | _BV(PIN_BUS2) | _BV(PIN_BUS3) | _BV(PIN_BUS4) | _BV(PIN_BUS5) | _BV(PIN_BUS6) | _BV(PIN_BUS7))

// Bus clock

#define PIN_DCLK           PORTB0
#define PIN_DCLK_PORT      PORTB
#define PIN_DCLK_PIN       PINB
#define PIN_DCLK_DDR       DDRB

// Frame clock

#define PIN_FCLK           PORTC3
#define PIN_FCLK_PORT      PORTC
#define PIN_FCLK_PIN       PINC
#define PIN_FCLK_DDR       DDRC

// SPI + SD card

#define PIN_SD_CD          PORTB1
#define PIN_SD_CD_PORT     PORTB
#define PIN_SD_CD_PIN      PINB
#define PIN_SD_CD_DDR      DDRB

#define PIN_SD_CS          PORTB2
#define PIN_SD_CS_PORT     PORTB
#define PIN_SD_CS_PIN      PINB
#define PIN_SD_CS_DDR      DDRB

#define PIN_MOSI          PORTB3
#define PIN_MOSI_PORT     PORTB
#define PIN_MOSI_PIN      PINB
#define PIN_MOSI_DDR      DDRB

#define PIN_MISO          PORTB4
#define PIN_MISO_PORT     PORTB
#define PIN_MISO_PIN      PINB
#define PIN_MISO_DDR      DDRB

#define PIN_SCK           PORTB5
#define PIN_SCK_PORT      PORTB
#define PIN_SCK_PIN       PINB
#define PIN_SCK_DDR       DDRB

// I2C

#define PIN_SDA           PORTC4
#define PIN_SDA_PORT      PORTC
#define PIN_SDA_PIN       PINC
#define PIN_SDA_DDR       DDRC

#define PIN_SCL           PORTC5
#define PIN_SCL_PORT      PORTC
#define PIN_SCL_PIN       PINC
#define PIN_SCL_DDR       DDRC

// IO interrupt

#define PIN_IO_INT        PORTC0
#define PIN_IO_INT_PORT   PORTC
#define PIN_IO_INT_PIN    PINC
#define PIN_IO_INT_DDR    DDRC

// LED

#define PIN_LED           PORTC1
#define PIN_LED_PORT      PORTC
#define PIN_LED_PIN       PINC
#define PIN_LED_DDR       DDRC

// Channel reset

#define PIN_CH_RESET      PORTC2
#define PIN_CH_RESET_PORT PORTC
#define PIN_CH_RESET_PIN  PINC
#define PIN_CH_RESET_DDR  DDRC



#endif

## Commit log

2016-11-23 * Added a menu system * Added an 8 Hz system timer * Refactoring
2017-06-13 Rewrite main interrupt in assembler
2017-06-15 Fixed a few bugs
    [interrupt.asm, main.c]
2017-06-30 Fixed a glitch in the output of the pulse and noise channels
    When the volume was changed while the channel was outputting a high,
    the wrong volume was ouput until the next time the output went low.
    Previously the volume was simply ORed into the output register, but
    now the register is first cleared.
    [interrupt.asm]
2017-07-07 * Update period of triangle channel when lower byte is changed This fixes a sound issue in Mega Man II
    [main.c]
2017-07-07 * Add ssd1306_puts_P to print string from flash * Fixed a bug in ssd1306_text_putc A missing cast prevented characters larger than 127 to print correctly
2017-07-08 * Add fuse data to makefile
2017-07-11 * Fixed missing 0 at end of filename * Added some extra comments
    [main.c]
2017-07-11 * Don't hardcode line width in the menu code * Got the previous position when the current position has disappeared
2017-07-15 * Added schematics and PCB layouts (Rev A)
    [IO.sch, audio.sch, channel.kicad_pcb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]
2017-07-16 * Corrected the duty cycle setting when mode=11
    [main.c]
2017-07-18 * Maintain a fixed frame rate to allow for silent frames
2017-07-19 * Fix detection of empty frames in nsf_play
2017-07-20 * Let bin_play loop the track
2017-07-20 * Find loop before playing and allow timeout in middle of track
2017-07-28 * Factored out some functions to handle frame updates
2017-10-04 * Save some cycles in the interrupt by using r6 as a fixed temporary register * Fixed a typo in main.c
    [interrupt.asm, main.c, registers.h]
2018-08-24 Script to analyse bank switching
2018-08-25 Refactored channel code
    - Introduced a union containing the lower and higher byte of the channel period
    - Improved assembly interrupt code
2018-08-25 Abstract out channel timer settings
